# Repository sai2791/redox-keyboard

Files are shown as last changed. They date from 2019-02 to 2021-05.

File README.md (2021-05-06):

<p align="center">
Redox logo
QMK

</p>

<h3 align="center">The Redox project repository</h3>

<div align="center">

[]()




</div>

---

The Redox project is an open-source, [QMK (Quantum Mechanical Keyboard Firmware)](https://github.com/qmk/qmk_firmware) powered, ergonomic split mechanical keyboard. This repository will be used to share information about the project and instruction on how to use and assemble the Redox keyboard.

<p align="center">
Redox
</p>

**Designer's bio**: [Mattia Dal Ben (aka u/TiaMaT102)](mailto:matthewdibi@gmail.com) obtained a master's degree in Electrical Engineering with a specialization in Computer Science at the University of Udine. Currently works as a Software Engineer in R&D department for a big IoT and Embedded Computers company. Mechanical keyboard enthusiast and maker, the Redox keyboard is the result of all of his passions.

## Rationale

The Redox is a keyboard project designed with ergonomics in mind. It uses Cherry MX style mechanical switches laid out in a 7x5 columnar stagger layout with components that can easily be sourced.

The design was heavily inspired by the [Ergodox keyboard](https://www.ergodox.io/), and its main goal is to reduce the size without sacrificing too many keys, hence the name **Re**duced Ergo**dox**.

As an Ergodox user I couldn't ignore the few flaws of the original design and in a moment of arrogance I tried to fix them, thus the Redox features:
- Easier to reach thumb cluster.
- Additional easy-to-reach rotated 1.25u thumb key.
- Reduced size.
- Reduced costs (the Redox uses Arduino Pro Micro instead of the Teensy 2.0).
- Either half can be plugged in to the PC since each half can act as the master.
- Either half can work as a standalone keyboard to be used as a macropad/gaming keyboard.
- RGB backlighting support.
- 3D-printer friendly case.
- Wireless
- [VIA](https://caniusevia.com/) compatible (thanks to [Harshit Goel](https://github.com/harshitgoel96))

## Related projects

- [**Redox handwire**](https://www.thingiverse.com/thing:2704567): The first incarnation of the Redox keyboard. It consists of a 3D-printed case and a handwired matrix.
  - [Tilted Redox case](https://www.thingiverse.com/thing:2767216): tilted case for the Redox prototype by jschloer.
  - [couscous-kbd](https://gitlab.com/cschalkwijk/couscous-kbd): Redox-inspired parametric OpenSCAD keyboard design.
  - [Redox tenting kit](https://www.thingiverse.com/make:484843): modified base to support tenting, mini-USB for the interconnect, and a hole for microswitch for reset needed when uploading new firmware by [Lenbok](https://github.com/Lenbok).
  - [Iris-inspired Redox case](https://github.com/Lenbok/scad-redox-case): a case inspired both by the Redox rev1.0 and the Iris designed with OpenSCAD by [Lenbok](https://github.com/Lenbok).
  - [Redodactyl keyboard](https://www.reddit.com/r/MechanicalKeyboards/comments/9j5pw5/enter_the_redodactyl_first_build/): handwired 3D printed Dactyl-inspired Redox variant by u/darknao.
- [**Redox Manuform**](https://www.thingiverse.com/thing:3503380): full rework of the Redox case inspired by the Dactyl Manuform. Designed by [Fosk\_LL](https://www.thingiverse.com/Fosk_LL/about).
- [**Redox rev1.0**](https://github.com/mattdibi/redox-keyboard/tree/master/redox): the Redox rev 1.0 is the first commercially available version of the Redox keyboard.
	- Rev1.0 PCBs: available at [Falbatech's store](https://falba.tech/product/redox-pcb-electrical-boards-set-of-2/)
    - Firmware sources:
        - [QMK firmware for Redox](https://github.com/mattdibi/qmk_firmware/tree/master/keyboards/redox)
	- 3D-printable cases:
        - [3D printable case](https://www.thingiverse.com/thing:2886662), freely available.
        - [Redox keyboard case (high profile)](https://www.thingiverse.com/thing:3825752), by [Michele Ferri](https://www.thingiverse.com/sako83/about).
        - [Travel-friendly Redox Keyboard case](https://www.thingiverse.com/thing:3607303), by [Fosk\_LL](https://www.thingiverse.com/Fosk_LL/about).
        - [Redox Neodox case](https://github.com/Pastitas/Redox-neodox-Case), by [Pastitas](https://github.com/Pastitas)
	- Commercially available cases:
		- [Falbatech's bamboo cases with tilt kit](https://falba.tech/product/redox-standard-lift-bamboo-wood-case-with-oil-finish/)
		- [Falbatech's fullhand bamboo cases](https://falba.tech/product/redox-fullhand-bamboo-wood-case-with-oil-finish-ver-2/)
		- [Falbatech's PVC cases](https://falba.tech/product/redox-standard-pvc-white-case/)
- [**Redox rev1.0W**](https://github.com/mattdibi/redox-keyboard/tree/master/redox-w): the Redox rev 1.0W is the wireless version of the Redox keyboard.
    - Rev1.0W PCBs: available at [Falbatech's store](https://falba.tech/product/redox-wireless-pcb-electrical-boards-set-of-2/)
    - Firmware sources:
        - [QMK firmware for Redox wireless](https://github.com/mattdibi/qmk_firmware/tree/master/keyboards/redox_w)
        - [Nordic MCUs firmware for Redox wireless](https://github.com/mattdibi/redox-w-firmware)
	- 3D-printable cases:
        - [3D printed case](https://github.com/mattdibi/redox-keyboard/tree/master/redox-w/case), freely available.
        - [Redox Neodox case](https://github.com/Pastitas/Redox-neodox-Case), by [Pastitas](https://github.com/Pastitas)
    - Commercially available cases:
        - [Falbatech's bamboo and aliminium cases](https://falba.tech/product/redox-wireless-standard-lift-bamboo-wood-case-with-oil-finish/)
		- [Falbatech's fullhand bamboo cases](https://falba.tech/product/redox-wireless-standard-lift-bamboo-wood-case-with-oil-finish-ver-1/)
		- [Falbatech's PVC cases](https://falba.tech/product/redox-wireless-standard-pvc-white-case/)
- [**Redox rev2.0WHS**](https://github.com/mattdibi/redox-keyboard/tree/master/redox-w): the Redox rev 2.0WHS is the wireless hot-swappable version of the Redox keyboard.
    - Rev2.0WHS PCBs: gerber files available [here](https://github.com/mattdibi/redox-keyboard/tree/master/redox-w/rev2.0WHS/pcb)
    - Firmware sources:
        - [QMK firmware for Redox wireless](https://github.com/mattdibi/qmk_firmware/tree/master/keyboards/redox_w)
        - [Nordic MCUs firmware for Redox wireless](https://github.com/mattdibi/redox-w-firmware)
	- 3D-printable case:
        - [3D printed case](https://github.com/mattdibi/redox-keyboard/tree/master/redox-w/rev2.0WHS/case), freely available.

## Layout

<p align="center">
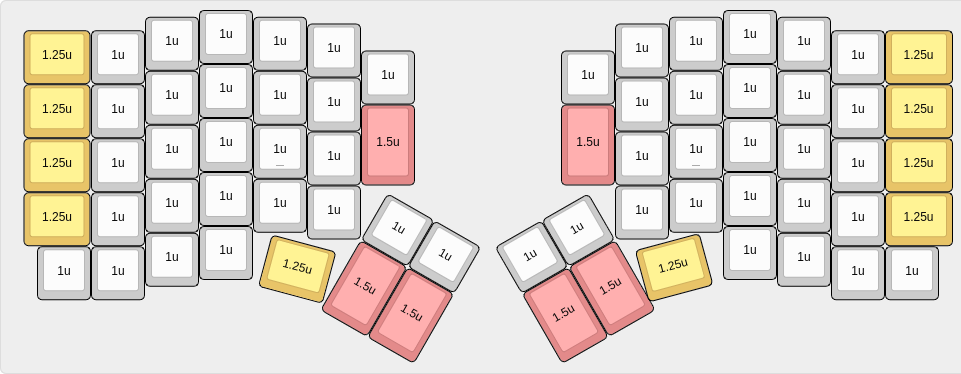
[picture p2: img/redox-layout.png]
Redox layout

</p>

### Keycaps

| Size  | Qty | Notes |
|---|:---:|:---:|
| 1.5u  | 6 | |
| 1.25u |  10 | You can get away with 8 if you use two 1u keycaps for the 1.25u rotated keys |
| 1u |  54 | |

> :information_source: On [pimpmykeyboard.com](https://pimpmykeyboard.com/sa-1976-keyset-two-shot/) site you can find a SA 1976 keyset kit specifically made for the Redox keyboard: the "Ergo Redox kit (12 keys)".

## Affiliations

In partnership with Falbatech you can now use the code "**mattdibi05**" on Falbatech's store for a 5% OFF special discount.

## Donations

If you've read this far and found something useful, please consider donating to help me maintain and further develop this project.

<p align="center">
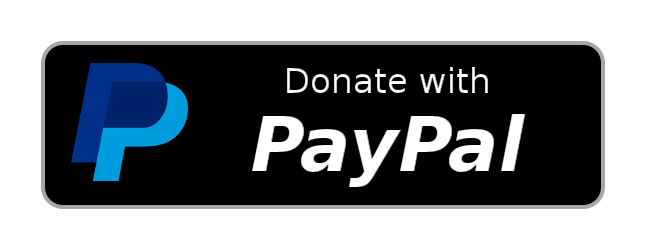
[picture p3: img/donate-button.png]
Donate button

</p>

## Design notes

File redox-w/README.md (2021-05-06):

## Redox-W (Wireless)

The Redox-W is the wireless version of the Redox keyboard, it comes in two flavours:

- **Rev 1.0W**: The first revision of the Redox Wireless.
- **Rev 2.0WHS**: Hot-swappable version of the Redox Wireless. It comes with some range improvements and limited compatibility with Rev1.0W cases (more on that in the [dedicated section](#case-compatibility)).

The two hardware revision share the firmware and the receiver dongle. In this page you'll find assembly instructions for both versions of the keyboard.

## Summary

  - [Bill of materials](#bill-of-materials)
  - [Receiver Assembly](#receiver-assembly)
  - [Transmitters Assembly](#transmitters-assembly)
    - [Rev 1.0W transmitters assembly](#rev-10w-transmitters-assembly)
    - [Rev 2.0WHS transmitters assembly](#rev-20whs-transmitters-assembly)
  - [Firmware](#firmware)
  - [Battery usage](#battery-usage)
  - [Case compatibility](#case-compatibility)

## Bill of materials

#### Transmitters

| Qty | Item | Notes |
|----:|---|---|
| 2 | Redox Wireless Transmitters PCB | Available versions: [Rev.1.0W](https://falba.tech/), [Rev.2.0WHS](https://www.pcbway.com/project/shareproject/Redox_Wireless_rev2_0WHS.html) |
|  70 | Cherry MX compatible switches | |
|  70 | Kailh PCB sockets CPG151101S11 | Rev.2.0WHS **only** |
| 2 | YJ-14015 modules (Core51822B clones) | [aliexpress](https://www.aliexpress.com/item/NRF51822-Core51822-BLE-4-0-Bluetooth-2-4G-Wireless-Module-Antenna-Board-For-ULP-SPI-I2C/32842154172.html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,searchweb201602_1_10065_10068_10843_10059_10884_10887_10696_100031_10084_10083_10103_10618_10304_10307_10820_10821_10302,searchweb201603_60,ppcSwitch_5&algo_expid=1dded059-5054-4890-bcc4-6face1150a21-1&algo_pvid=1dded059-5054-4890-bcc4-6face1150a21&priceBeautifyAB=0)
|  70 | SOD-123 1N4148/1N4148W diodes | 1N4148 THT diodes can also be used |
| 2 | Keystone 3034 SMT battery holders | [digikey](https://www.digikey.com/product-detail/en/keystone-electronics/3034/36-3034-ND/4499289)|
| 2 | JS102011SAQN SMT slide switch | [digikey](https://www.digikey.com/product-detail/en/c-k/JS102011SAQN/401-1999-1-ND/1640114)|
| 2 | Right angle 0.1" header (1x4pin) | |

#### Receiver

| Qty | Item | Notes |
|----:|---|---|
| 1 | Redox receiver PCB | [PCB manufacturing link](https://www.pcbway.com/project/shareproject/Redox_Wireless_Receiver.html) |
| 1 | YJ-14015 module (Core51822B clone) | [aliexpress](https://www.aliexpress.com/item/NRF51822-Core51822-BLE-4-0-Bluetooth-2-4G-Wireless-Module-Antenna-Board-For-ULP-SPI-I2C/32842154172.html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,searchweb201602_1_10065_10068_10843_10059_10884_10887_10696_100031_10084_10083_10103_10618_10304_10307_10820_10821_10302,searchweb201603_60,ppcSwitch_5&algo_expid=1dded059-5054-4890-bcc4-6face1150a21-1&algo_pvid=1dded059-5054-4890-bcc4-6face1150a21&priceBeautifyAB=0) |
| 1 | Arduino Pro Micro compatible microcontroller  | |
| 1 | 1117 3.3v regulator in SOT223 | [digikey](https://www.digikey.com/product-detail/en/diodes-incorporated/AZ1117IH-3.3TRG1/AZ1117IH-3.3TRG1DICT-ND/5699682)|
| 2 | 330 Ohm 0805(2012 metric) SMD resistors | Default configuration. Values depends on LED color, see [below](#resistor-values)|
| 2 | 220 Ohm 0805(2012 metric) SMD resistors | Default configuration. Values depends on LED color, see [below](#resistor-values)|
| 3 | 1.5k Ohm 0805(2012 metric) SMD resistors | Default configuration. See [below](#resistor-values)|
| 1 | Red 0805(2012 metric) SMD standard LED | Default configuration. |
| 1 | Blue 0805(2012 metric) SMD standard LED | Default configuration. |
| 1 | Green 0805(2012 metric) SMD standard LED | Default configuration. |
| 1 | White 0805(2012 metric) SMD standard LED | Default configuration. |
| 1 | Through hole momentary switch | Dimensions 6mm x 6mm x 4.3mm |
| 1 | Right angle 0.1" header (1x4pin) | |
| 2 | Straight 0.1" header (1x6pin) | |

> :information_source: You can also use the [Mitosis receiver](https://github.com/reversebias/mitosis-hardware/blob/master/bom/README.md) since it's almost identical, or you can build a receiver on your own.

> :warning: To program the YJ-14015 MCUs you need an ST-Link v2 programmer, these can be found on eBay or Aliexpress for as little as 2$ shipped. See [picture below](#nordic-mcus-firmware).

##### Resistor values

If you want to customize your LEDs color or save a few bucks by ordering the LED all the same color you can refer to this section for choosing the correct resistor values. Otherwise you can refer to the [default configuration](#default-configuration).

There are two sets of resistor that you need for the receiver.

- The voltage divider resistors (`R1`, `R2` and `R3`): anything between 1.5k Ohm and 4.7k Ohm is good.
- The LEDs resistors (`R4`,`R6`,`R7` and `R8`): see the following table.

| LED color | Vf | Suggested resistor value |
|---|---|---|
| Red | 1.7V | 330 Ohm |
| Yellow | 2.1V | 330 Ohm |
| Blue | 3.2V | 220 Ohm |
| Green | 2.2V | 330 Ohm |
| White | 3.6V | 220 Ohm |

Depending on the color you choose to use you should use the resistor listed above.

#### Default configuration

Here you can find the default configuration for the receiver assembly.

| Label | Component |
|---|---|
| D1 | Red LED |
| D2 | Blue LED |
| D3 | Green LED |
| D4 | White LED |
| R4 |  330 Ohm resistor |
| R6 |  220 Ohm resistor |
| R7 |  330 Ohm resistor |
| R8 |  220 Ohm resistor |
| R1 | 1.5k Ohm resistor |
| R2 | 1.5k Ohm resistor |
| R3 | 1.5k Ohm resistor |

## Receiver Assembly

The receiver assembly is pretty straightforward, you can install the components in any order you like with the exception of the YJ-14015: it should be installed **after** the right angled header (PROGR_HEADER1). Suggested assembly order:

1. Solder D1, D2, D3 and D4 LEDs. See [image](#leds-installation-detail) for orientation.
2. Solder R4, R6, R7 and R8 resistors.
3. Solder R1, R2 and R3 resistors.
4. Solder the AMS1117.
5. Solder the Arduino Pro Micro headers.
6. Solder the programming headers. I suggest you to cut the excess of the header **before** soldering the headers. You should stay as flush to the PCB surface as possible since the controller will be soldered above the headers. Use some masking tape to help you keep the header in place while soldering.
7. Solder the YJ-14015. I suggest you to glue it in place or use some masking tape to help you during soldering.
8. Upload the firmware and you're done.

##### Assembled PCB, front

<p align="center">
Assembled receiver PCB, front.
</p>

##### Assembled PCB, back

<p align="center">
Assembled receiver PCB, back.
</p>

##### LEDs installation detail

<p align="center">
Assembled receiver PCB, LEDs installation detail.
</p>

> :information_source: Please note that here I installed 220 Ohm resistors because I used only blue and white LEDs as I only had those laying around. You should use the resistor values suggested [here](#resistor-values) or follow the [default configuration](#default-configuration).

## Transmitters Assembly

### Rev 1.0W transmitters assembly

<p align="center">
Wireless redox PCBs
</p>

Assembly steps:

- Solder components to PCBs (you can proceed in no particular order):
  1. Solder the YJ-14015.
  2. Solder 1N4148 diodes.
  3. Solder slider switches.
  4. Solder the battery holders. *Note*: Some solder is needed on the ground pad to contact properly with the battery. See [picture below](#battery-holder-installation-detail).
  5. Solder the programming headers.
- Fit the PCBs inside their cases.
- Add the switches to the plate.
- Solder switches to the PCB.
- Add the CR2032 batteries.
- Program the MCUs.
- Close the case.

##### Programming headers detail

<p align="center">
Programming headers detail
</p>

##### MCUs detail

<p align="center">
MCUs detail
</p>

##### Slider switch detail

<p align="center">
Slider switch detail
</p>

##### Diodes installation detail

<p align="center">
Diode installation detail
</p>

##### Battery holder installation detail

<p align="center">
Battery holder installation detail. Ground pad.
Battery holder installation detail. Assembled.
</p>

##### Left and right hand completed assembly

<p align="center">
Left and right hand completed assembly
</p>

##### Assembled PCB

<p align="center">
Wireless Redox assembled PCB
</p>

### Rev 2.0WHS transmitters assembly

<p align="center">
Redox 2.0WHS PCBs, unassembled.
</p>

Suggested assembly order (there's no wrong way of doing this because all parts can be soldered in any order):
1. Solder the YJ-14015.
2. Solder the right angle 0.1" header. To test the solder job try uploading the firmware as described in the dedicated section.
3. Solder the diodes taking into account the right orientation. The cathode side (denoted by the vertical line on the packaging) should face the squared hole on the PCB. See the [pictures](#diodes-and-hot-swap-socket-detail) for reference. If you have already assembled the Redox receiver, you can now test if the PCB is working properly by connecting the STLinkV2 debugger for supplying power to the transmitter and using a pair of pliers to short the Kailh socket pins.
4. Solder the Kailh hot-swap sockets.
5. Solder the battery holders.
6. Solder the slide switch.

##### MCUs detail

<p align="center">
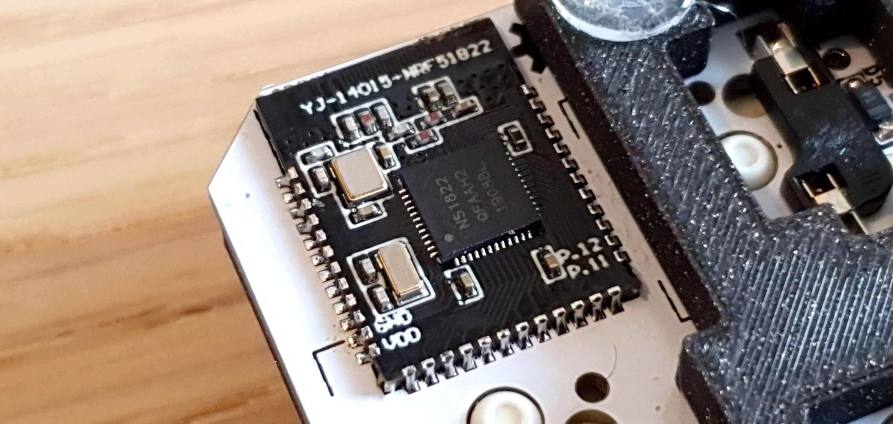
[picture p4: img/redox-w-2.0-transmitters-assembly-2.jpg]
MCUs detail 1

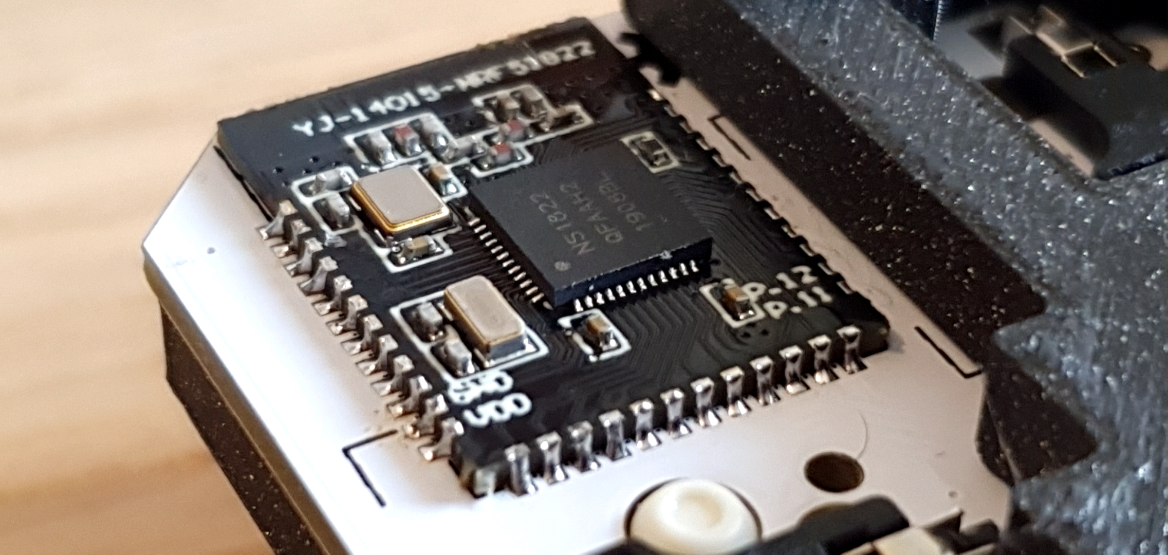
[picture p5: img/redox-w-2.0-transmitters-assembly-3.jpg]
MCUs detail 2

</p>

##### Diodes and hot-swap socket detail

<p align="center">
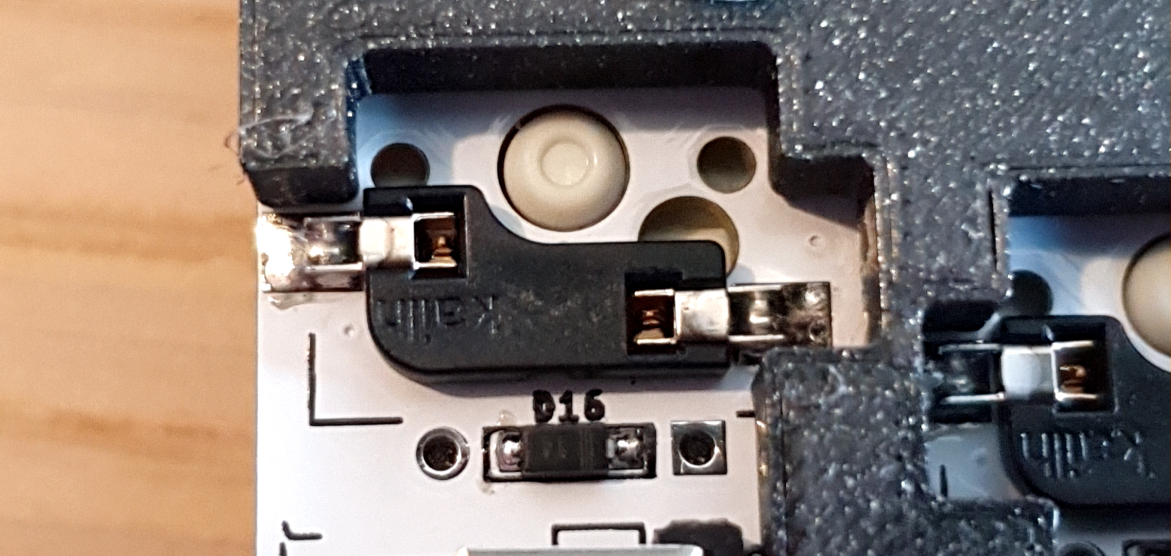
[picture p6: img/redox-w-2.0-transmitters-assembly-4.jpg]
Diode and hot-swap socket detail 1

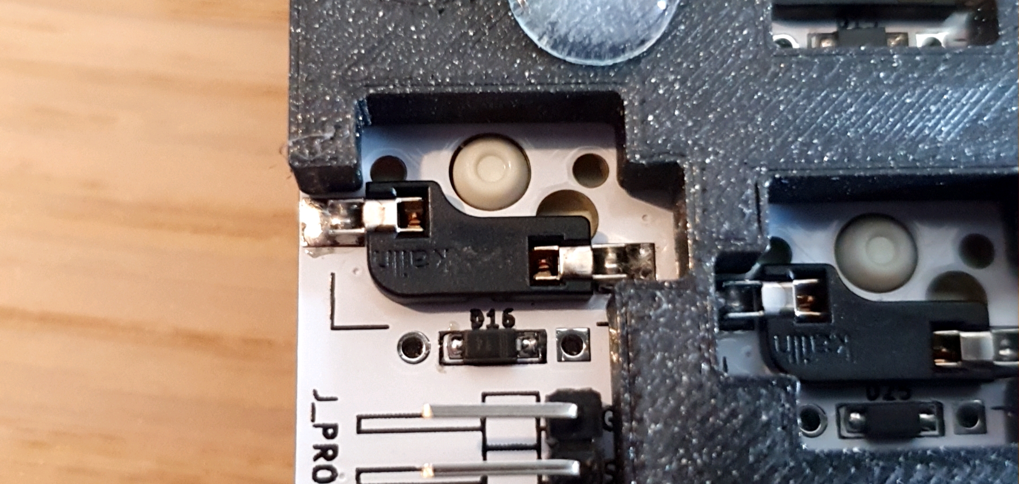
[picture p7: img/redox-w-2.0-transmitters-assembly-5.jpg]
Diode and hot-swap socket detail 2

</p>

##### Assembled PCB

<p align="center">
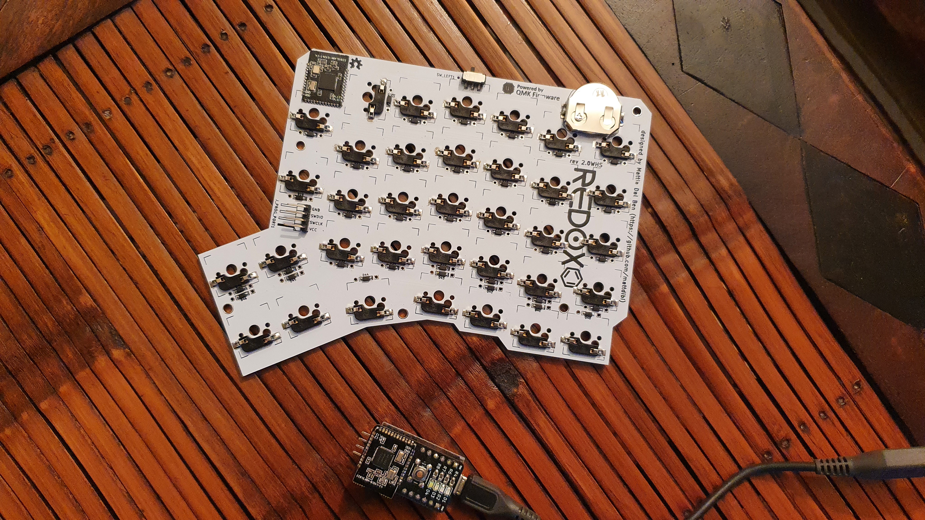
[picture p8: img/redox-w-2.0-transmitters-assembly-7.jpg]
Wireless Redox assembled PCB

</p>

##### Rev 2.0WHS 3D printed case

<p align="center">
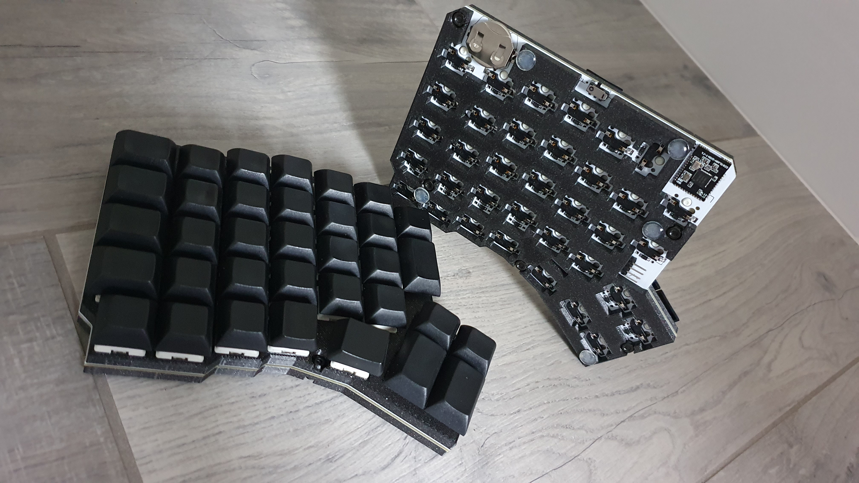
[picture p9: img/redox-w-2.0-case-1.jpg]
3D printed case

</p>

[Here](https://github.com/mattdibi/redox-keyboard/tree/master/redox-w/rev2.0WHS/case) you can find the newly designed case for the Redox 2.0 WHS. Features:
- Easy to print
- Sturdy feeling
- Minimal footprint
- Integrated sound dampening

I printed it with my Prusa Mini with 0.2 mm layer height. The STLs are for the left hand keyboard only, you'll need to mirror them along the X axis in your slicer for the right hand keyboard.

Hardware required for assembly:
- 10x M3 8 mm screws
- 10x M3 nuts

> :warning: The 3D printed case requires the use of SMD diodes. Through hole diodes will interfer witht the front plate.

> :warning: The closed back design (file: `BackplateL.stl`) was not tested at the time of this writing.

## Firmware

**Basics**: The Redox keyboard works similarly to the [Mitosis keyboard](https://github.com/qmk/qmk_firmware/tree/master/keyboards/mitosis): we have two transmitters responsible for scanning the two matrices, which then transmit the matrix status through the [Gazel protocol](https://developer.nordicsemi.com/nRF5_SDK/nRF51_SDK_v5.x.x/doc/5.2.0/html/a00140.html) to the receiver. The receiver is another YJ-14015 which receives the two matrix scans and send it through serial to the Arduino Pro Micro. The Pro Micro is responsible for running QMK and converting the bytes received by the YJ-14015 into actual keystrokes.

Firmware sources available here: [https://github.com/mattdibi/redox-w-firmware](https://github.com/mattdibi/redox-w-firmware).

You'll need to upload the firmware to the corresponding MCUs as per the following diagram:

<p align="center">
Redox-W firmware diagram.
</p>

Note that you'll need to upload the firmware for the YJ-14015 only once. Everything related to the keymap is handled by the Arduino Pro Micro and QMK Firmware, that's what you will need to modify to update the keymap.

### Step-by-step firmware upload guide

#### Arduino Pro Micro Firmware upload

Let's start by uploading the QMK firmware on the Arduino, this will help us in diagnosing problems early on. The Redox Wireless uses QMK for its firmware, follow the QMK installation instructions [here](https://docs.qmk.fm/#/getting_started_build_tools), then compile and burn the firmware as follows:

```sh
$ cd path/to/qmk_firmware
$ make redox_w:default:avrdude
```

You can find the code for the Redox here: [QMK - Redox Wireless keyboard](https://github.com/mattdibi/qmk_firmware/tree/redox_wireless/keyboards/redox_w).

In the [Redox Wireless Keyboard firmware repository](https://github.com/mattdibi/redox-w-firmware/tree/master/precompiled) I added some pre-built hex files with the default keymap for testing purposes.

#### Nordic MCUs Firmware upload using Docker

To flash the firmware files to the corresponding MCUs, you'll need an STLinkV2 debugger.

<p align="center">
ST-Link v2 programmer
</p>

##### Setup

###### Requirements

- Linux-based distro (macOS should work too but wasn't tested)
- [Docker](https://docs.docker.com/get-docker/)
- [Docker-compose](https://docs.docker.com/compose/install/)
- Download the [redox-w-firmware](https://github.com/mattdibi/redox-w-firmware) repository.

###### Download the repository

Open a terminal and download the Redox Wireless firmware repository wherever you want.

```
$ git clone https://github.com/mattdibi/redox-w-firmware.git
```

or

```
$ wget https://github.com/mattdibi/redox-w-firmware/archive/refs/heads/master.zip
```

###### Install the udev rules

Install the udev rules for the STLinkV2 programmer contained inside the repository.

```
$ cd path/to/repository/redox-w-firmare/
$ sudo cp 49-stlinkv2.rules /etc/udev/rules.d/
$ udevadm control --reload-rules && udevadm trigger
```

Plug in, or replug in the programmer after this.

###### Build the two container images

From inside the `redox-w-firmware` folder run:

```
$ docker-compose build
```

After the process completes you should see three new images:

```
$ docker images
REPOSITORY           TAG       IMAGE ID       CREATED          SIZE
redox-fw-toolchain   latest    810de995238e   16 minutes ago   896MB
redox-fw-openocd     latest    173d86d1409c   18 minutes ago   168MB
ubuntu               16.04     8185511cd5ad   4 weeks ago      132MB
```

##### Programming the receiver

###### Hook up the receiver

Hook up the ST-Link debugger to the receiver board you assembled without the Arduino. You need to connect only the `VCC`, `GND`, `SWDIO` and `SWCLK` pins of the receiver board like this:

| ST-Link Debugger | Receiver board |
|---|---|
| 3.3V | VCC |
| GND | GND |
| SWCLK | SWCLK |
| SWDIO | SWDIO |

<p align="center">
ST-Link debugger wiring.
</p>

Then plug in the ST-Link debugger into your PC.

###### Run the two images using docker compose

After connecting the STLinkV2 debugger, from inside the `redox-w-firmware` folder run:

```
$ docker-compose up
Creating redox-w-firmware_openocd_1 ... done
Creating redox-w-firmware_toolchain_1 ... done
Attaching to redox-w-firmware_openocd_1, redox-w-firmware_toolchain_1
openocd_1    | Open On-Chip Debugger 0.9.0 (2018-01-24-01:05)
openocd_1    | Licensed under GNU GPL v2
openocd_1    | For bug reports, read
openocd_1    | 	http://openocd.org/doc/doxygen/bugs.html
openocd_1    | WARNING: target/nrf51_stlink.cfg is deprecated, please switch to target/nrf51.cfg
openocd_1    | Info : auto-selecting first available session transport "hla_swd". To override use 'transport select <transport>'.
openocd_1    | Info : The selected transport took over low-level target control. The results might differ compared to plain JTAG/SWD
openocd_1    | adapter speed: 1000 kHz
openocd_1    | Info : Unable to match requested speed 1000 kHz, using 950 kHz
openocd_1    | Info : Unable to match requested speed 1000 kHz, using 950 kHz
openocd_1    | Info : clock speed 950 kHz
openocd_1    | Info : STLINK v2 JTAG v17 API v2 SWIM v4 VID 0x0483 PID 0x3748
openocd_1    | Info : using stlink api v2
openocd_1    | Info : Target voltage: 3.274320
openocd_1    | Info : nrf51.cpu: hardware has 4 breakpoints, 2 watchpoints
```

From another terminal window, you should see the two containers running with the following command:

```
$ docker ps
CONTAINER ID   IMAGE                       COMMAND                  CREATED         STATUS         PORTS     NAMES
84f606ad7e25   redox-fw-toolchain:latest   "tail -f /dev/null"      4 seconds ago   Up 3 seconds             redox-w-firmware_toolchain_1
8d0d6b5da95a   redox-fw-openocd:latest     "/bin/sh -c 'openocd…"   4 seconds ago   Up 3 seconds             redox-w-firmware_openocd_1
```

###### Build and upload the firmware

We can now build and upload the firmware by issuing the following from the `redox-w-firmware` root directory:

```
$ docker exec -it redox-w-firmware_toolchain_1 ./redox-w-firmware/redox-w-receiver-basic/program.sh
```

if everything goes well we should see the following output:

```
============================= PROGRAMMING =============================
Trying 127.0.0.1...
Connected to localhost.
Escape character is '^]'.
Open On-Chip Debugger
> reset halt
target state: halted
target halted due to debug-request, current mode: Thread 
xPSR: 0xc1000000 pc: 0x00000ba8 msp: 0x20004000
> flash write_image erase /usr/src/nRF5_SDK_11/redox-w-firmware/redox-w-receiver-basic/custom/armgcc/_build/nrf51822_xxac-receiver.hex
auto erase enabled
Unknown device (HWID 0x000000d1)
using fast async flash loader. This is currently supported
only with ST-Link and CMSIS-DAP. If you have issues, add
"set WORKAREASIZE 0" before sourcing nrf51.cfg to disable it
target state: halted
target halted due to breakpoint, current mode: Thread 
xPSR: 0x61000000 pc: 0x2000001e msp: 0x20004000
wrote 16384 bytes from file /usr/src/nRF5_SDK_11/redox-w-firmware/redox-w-keyboard-basic/custom/armgcc/_build/nrf51822_xxac-receiver.hex in 0.782274s (20.453 KiB/s)
> reset
> Connection closed by foreign host.

============================== FINISHED ===============================
```

while in the docker compose terminal we should see the following:

```
openocd_1    | Info : accepting 'telnet' connection on tcp/4444
openocd_1    | target state: halted
openocd_1    | target halted due to debug-request, current mode: Thread 
openocd_1    | xPSR: 0xc1000000 pc: 0x00000ba8 msp: 0x20004000
openocd_1    | auto erase enabled
openocd_1    | Warn : Unknown device (HWID 0x000000d1)
openocd_1    | Warn : using fast async flash loader. This is currently supported
openocd_1    | Warn : only with ST-Link and CMSIS-DAP. If you have issues, add
openocd_1    | Warn : "set WORKAREASIZE 0" before sourcing nrf51.cfg to disable it
openocd_1    | target state: halted
openocd_1    | target halted due to breakpoint, current mode: Thread 
openocd_1    | xPSR: 0x61000000 pc: 0x2000001e msp: 0x20004000
openocd_1    | wrote 16384 bytes from file /usr/src/nRF5_SDK_11/redox-w-firmware/redox-w-keyboard-basic/custom/armgcc/_build/nrf51822_xxac-receiver.hex in 0.782274s (20.453 KiB/s)
openocd_1    | Info : dropped 'telnet' connection
```

###### Shutdown the container and disconnect the programmer

We can now shutdown the containers by issuing a `Ctrl-C` inside the docker-compose terminal. After the command completes we can disconnect the STLinkV2 programmer and proceed to program the rest of the MCUs.

```
^CGracefully stopping... (press Ctrl+C again to force)
Stopping redox-w-firmware_toolchain_1 ... done
Stopping redox-w-firmware_openocd_1   ... done
```

##### Programming the two halves

###### Hook up the transmitter

Hook up the ST-Link programmer with the transmitters using the programming pins, and plug the debugger in you PC.

<p align="center">
Transmitters programming pins.
</p>

Start a OpenOCD session as seen [above](#run-the-two-images-using-docker-compose) using docker-compose and start flashing the firmware.

###### Left hand firmware flashing

From another terminal window issue the following command:

```
$ docker exec -it redox-w-firmware_toolchain_1 ./redox-w-firmware/redox-w-keyboard-basic/program_left.sh
```

You should see a similar output as above. You can now shutdown the two containers, disconnect the programmer and proceed with the next MCU.

###### Right hand firmware flashing

After having hooked up the right hand to the ST-Link debugger and started a new OpenOCD session we can upload the right hand firmware.

```
$ docker exec -it redox-w-firmware_toolchain_1 ./redox-w-firmware/redox-w-keyboard-basic/program_right.sh
```

Congratulations! You flashed the Redox-W firmware.

## Battery usage

I got the current consumption for the transmitters using a shunt resistor (10 Ohm) and an oscilloscope during transmission.

<p align="center">
Current draw for Redox-W transmitters
</p>

Data:
- Current peak of 5mA (I<sub>run</sub>) and 50us duration (t<sub>run</sub>)
- Idle consumption of 2.7uA (I<sub>idle</sub>) between peaks, that is 950us duration (t<sub>idle</sub>).

We can then calculate the average current consumption during typing (I<sub>avg</sub>) using the following:

<a href="https://www.codecogs.com/eqnedit.php?latex=I_{avg}&space;=&space;\frac{I_{run}t_{run}&plus;&space;I_{idle}t_{idle}}{t_{run}&plus;t_{idle}}&space;=&space;\frac{5{mA}*50{\mu&space;A}&plus;2.7{\mu&space;A}*950{\mu&space;s}}{1ms}&space;\simeq&space;250&space;\mu&space;A" target="_blank">I_{avg} = \frac{I_{run}t_{run}+ I_{idle}t_{idle}}{t_{run}+t_{idle}} = \frac{5{mA}*50{\mu s}+2.7{\mu A}*950{\mu s}}{1ms} \simeq 250 \mu A</a>

Knowing that the CR2032 battery is rated for 220mAh we get:

<a href="https://www.codecogs.com/eqnedit.php?latex=t_{batt}&space;=&space;\frac{C_{batt}}{I_{avg}}&space;=&space;\frac{220{mAh}}{250{\mu&space;A}}&space;\simeq&space;880h" target="_blank">t_{batt} = \frac{C_{batt}}{I_{avg}} = \frac{220{mAh}}{250{\mu A}} \simeq 880h</a>

**TLDR**: We can expect **at least 880 hours** of continuous typing on the keyboard before needing to change the batteries. Keep in mind that when you're not typing (500ms without key presses is the time interval needed for the keyboard) the transmitters go into deep sleep mode and draw only 2.7uA. So for an everyday use (4 hours a day of continuous typing) you can expect a battery life of at least a year. Obviously your mileage may vary.

> :information_source: After using my keyboard for a few years I can confirm that battery usage matches the above computations. Please note that a metallic case can greatly impact user experience and battery usage.

## Case compatibility

Revision 1.0W and 2.0WHS share a lot of similarities with the exception of a single mounting hole.

<p align="center">
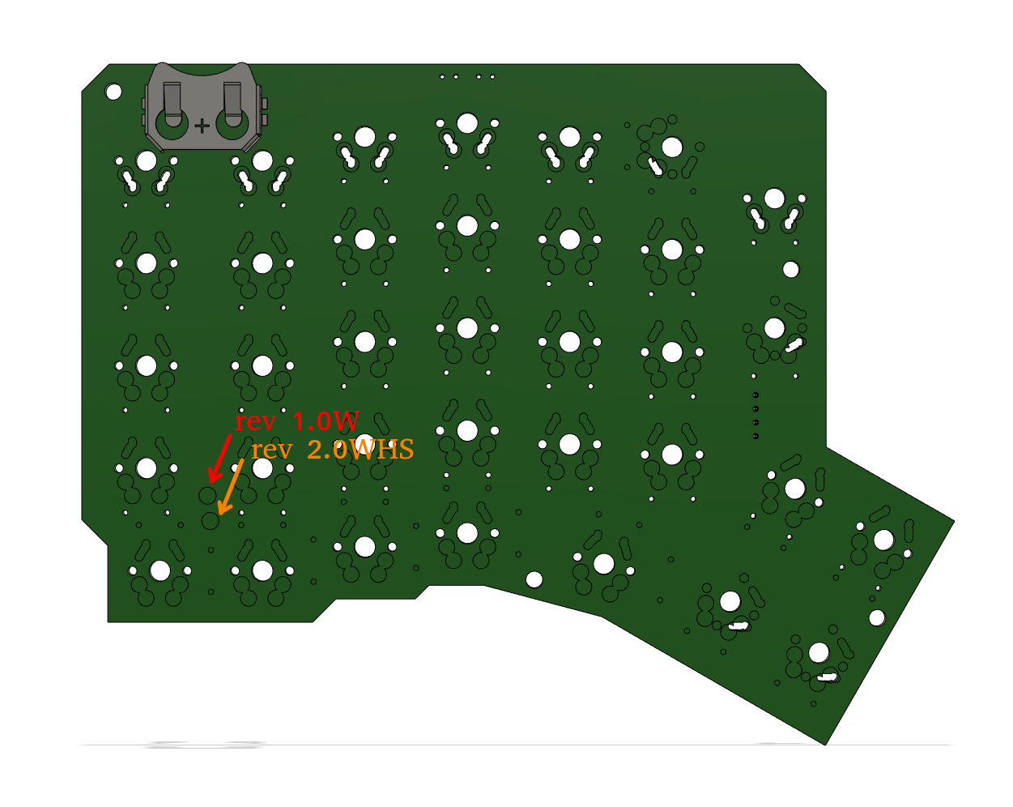
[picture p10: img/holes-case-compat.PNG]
Redox-W revisions compatibility.

</p>

As you can see from the above image, the mounting hole was moved a little lower in the rev 2.0WHS. This shouldn't compromise usability and fitment but take this into account if you want to fit a 2.0WHS PCB into a 1.0W case or vice-versa.

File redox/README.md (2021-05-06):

# Redox rev 1.0

The Redox rev 1.0 is the first commercially available version of the Redox keyboard.

Hardware availability:
  - [Falbatech](https://falba.tech/)

## Summary

  - [Bill of materials](#bill-of-materials)
  - [Other assembly guides](#other-assembly-guides)
  - [Assembly guide](#assembly-guide)
  - [Firmware](#firmware)
  - [Hot swappable mod](#hot-swappable-mod)
  - [RGB Underglow](#rgb-underglow)

## Bill of materials

| Qty | Item | Notes |
|----:|---|---|
|  70 | Cherry MX compatible switches | |
| 2 | Redox PCBs | [Available here](https://falba.tech/product/redox-pcb-electrical-boards-set-of-2/)|
|  70 | 1N4148 diodes | SMD diodes can also be used |
| 2 | PJ-320A 4 poles 3.5 mm TRRS connectors | |
| 2 | 4.7 kOhm resistors | Need to be soldered on one half only |
| 2 | Through hole momentary switch | Dimensions 6mm x 6mm x 4.3mm |
| 2 | Arduino Pro Micro compatible microcontrollers | Beware of the infamous Green Pro Micro, see note below. |
| 1 | TRRS cable | |
| 1 | USB micro cable | |
|  70 | Cherry MX compatible keycaps | 10x 1.25u keycaps, 6x 1.5u keycaps, 54x 1u keycaps  |
|  14 | WS2812/WS2812B leds | Optional RGB-underglow |

> :warning: Pay attention to the Pro Micro you use in this project. Online you can find the infamous **Green Pro Micros** which have the same pinout of the normal Pro Micro but use a different power circuitry. Being the Redox a split keyboard that relies on detecting which side is directly powered to find which side is the master, these clones are not suited for the task. A more detailed explanation [here](http://www.40percent.club/2017/09/green-pro-micro.html). Please note that they can come in different colors, not necessarily green.

## Other assembly guides

External links to some other guides to building the Redox keyboard:

- ["*Build your own keyboard*"](https://medium.com/@costask/build-your-own-keyboard-5df65cb68839) by @costask.
- [Imgur build log](https://imgur.com/a/a6ck2Nc) (3D printed case).
- ["*First Homebrew Keyboard -redox Build Log-*"](https://x1.inkenkun.com/archives/6007) by [インケンch](https://www.youtube.com/channel/UCXJZdip7JmW74HQHCtfYzFw) (Japanese only)
- ["*Split Keyboard Build*"](https://kubami.com/articles/split-keyboard-build/) by Kuba Misiorny @kubami.

### Video guides

Two great video guides by [インケンch](https://www.youtube.com/channel/UCXJZdip7JmW74HQHCtfYzFw) (Japanese only).

<p align="center">
<a href="http://www.youtube.com/watch?v=EVRlU_eR9j4">Redox hardware assembly</a>
<a href="http://www.youtube.com/watch?v=jRIRdfIIa1Q">Redox firmware</a>
</p>

Another great guide by [Antonio Raptors](https://www.youtube.com/channel/UCNYbiq6AH8AdYTKMokKaviQ) (Spanish only).

<p align="center">
<a href="https://www.youtube.com/watch?v=wRvfs1tUpZ4">Como hacer un teclado mecánico para diseño / gaming - REDOX ESPAÑOL</a>
</p>

## Assembly guide

<p align="center">
Redox PCBs
</p>

Installation steps:

- Solder components:
  1. Solder 1N4148 diodes. Keep the diode legs for the right hand controller installation.
  2. Solder PJ-320A connectors.
  3. Solder momentary switches.
  4. Solder 4.7k Ohm resistors **on one half only**. If you are going for the RGB-underglow ignore this step.
  5. Solder the Pro Micro header pins (**do not solder the Pro Micro controllers yet**). This step may differ depending on which case you're using. Refer to the following:
    * See 3D-Printed case [right hand controller installation detail](#3d-printed-case-assembly).
    * See Falbatech's [bamboo case](#falbatechs-bamboo-case-assembly).
    * See [socketed Pro Micro installation guide](#pro-micro-sockets).
  6. Optional see [RGB-underglow instructions](#rgb-underglow).
- Flip the PCBs.
- Solder switches to the PCB.
  * If you want hot swappable switches, see
    [the hot swappable switch instructions](#hot-swappable-switches).
- Flip the PCBs again.
- Solder Pro Micros to the header pins **following the PCB labeling**. The Pro Micro on the right half should be installed with the bottom facing the Redox PCB, the Pro Micro on the left half should be installed with the bottom facing away from the PCB. See [pictures](#left-hand-back-side-1) for details.

##### Right hand back side:
<p align="center">
Right hand back side
</p>

##### Left hand back side:
<p align="center">
Left hand back side
</p>

##### Diode installation detail:
<p align="center">
Diode installation detail
</p>

### 3D Printed case assembly

To lower the build costs I designed a 3D printable case which you can find in this repository or on [thingiverse](https://www.thingiverse.com/thing:2886662), feel free to modify it to best suit your needs.

<p align="center">
3D printed case
</p>

Parts:

| Qty | Item | Notes |
|----:|---|---|
| 1 | Left top plate | [RedoxRev1TopLeft.STL](https://github.com/mattdibi/redox-keyboard/blob/master/redox/case/RedoxRev1TopLeft.STL)|
| 1 | Left bottom | [RedoxRev1BottomLeft.STL](https://github.com/mattdibi/redox-keyboard/blob/master/redox/case/RedoxRev1BottomLeft.STL)|
| 1 | Right top plate | [RedoxRev1TopRight.STL](https://github.com/mattdibi/redox-keyboard/blob/master/redox/case/RedoxRev1TopRight.STL)|
| 1 | Right bottom | [RedoxRev1BottomRight.STL](https://github.com/mattdibi/redox-keyboard/blob/master/redox/case/RedoxRev1BottomRight.STL)|
|  10 | M3 x 8mm (or 5mm) screws | |

For the Pro Micro installation on the right hand use the diodes legs leftover from previous steps as this will make the controller's USB port much closer to the PCB, this is needed for the USB connector to fit in the 3D printed case. If you're using Falbatech's bamboo case this is not needed and you can use standard header pins. Right hand controller installation detail:

1. Use a breadboard to keep the diode's legs from falling.
2. Solder the diode's legs in place. You want to have the Pro Micro as close to the Redox's PCB as possible.
3. Cut the excess.
4. Apply some electrical tape under the controller to prevent shorts.
5. Install your preferred switches (**remember: the controller installation is the last step**).
6. Solder the controllers in place.

<p align="center">
Right hand controller installation detail
Right hand controller installation detail
</p>

Here's some measurements of the Pro Micro installation:

<p align="center">
Right hand controller installation detail
</p>

### Falbatech's bamboo case assembly

If you're using Falbatech's bamboo case the use of the diode's legs is not needed and you can use standard header pins

<p align="center">
Falbatech's case assembly
</p>

## Firmware

> :warning: If you have a Redox with RGB backlight installed you **MUST** use the serial connection. For details see [the RGB underglow firmware instructions.](#rgb-underglow)

The Redox uses QMK for its firmware, follow the QMK installation instructions [here](https://docs.qmk.fm/#/getting_started_build_tools), then compile and burn the firmware on both halves as follows:

```sh
$ cd path/to/qmk_firmware
$ make redox/rev1:default:avrdude
```

After issuing this command you should see the following output:

```sh
Detecting USB port, reset your controller now.....
```

Now you should reset the Pro Micros using the reset button as seen in the following picture:

<p align="center">
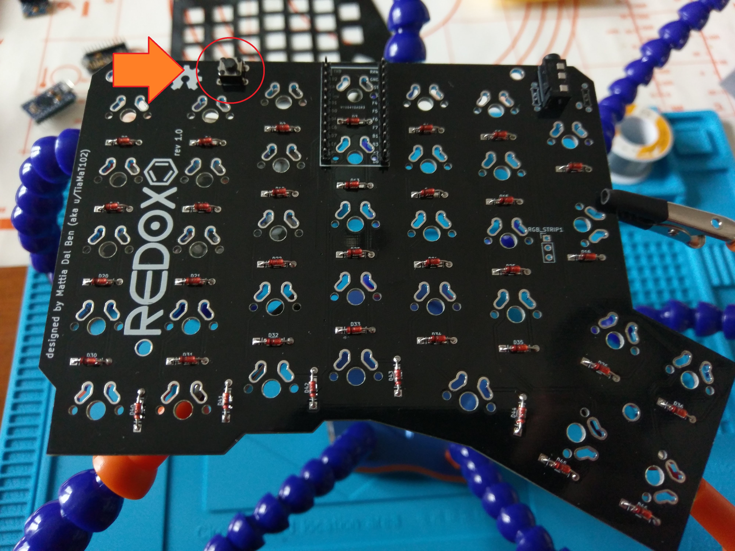
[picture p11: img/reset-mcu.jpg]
Reset button

</p>

> :warning: You always need to burn the firmware on **BOTH** halves of the keyboard.

> :warning: Failing to upload Redox Firmware on Linux. Please refer to [issue #8060](https://github.com/qmk/qmk_firmware/issues/8060) of QMK firmware.

You can find the code for the Redox here: [QMK - Redox keyboard](https://github.com/qmk/qmk_firmware/tree/master/keyboards/redox).

In the [firmware/](https://github.com/mattdibi/redox-keyboard/tree/master/redox/firmware) folder I added some pre-built hex files with the default keymap for testing purpose. You can upload the firmware binaries directly using the command below:

```sh
avrdude -p atmega32u4 -P $(COM_PORT) -c avr109 -U flash:w:redox_rev1_default.hex
```

### Setting EE_hands to use either hands as master
If you define `EE_HANDS` in your `config.h`, you will need to set the EEPROM for the left and right halves.

The EEPROM is used to store whether the half is left handed or right handed. This makes it so that the same firmware file will run on both hands instead of having to flash left and right handed versions of the firmware to each half. To flash the EEPROM file for the left half run:
```
$ cd path/to/qmk/folder
avrdude -p atmega32u4 -P $(COM_PORT) -c avr109 -U eeprom:w:"./quantum/split_common/eeprom-lefthand.eep"
// or the equivalent in dfu-programmer
```
and similarly for right half
```
avrdude -p atmega32u4 -P $(COM_PORT) -c avr109 -U eeprom:w:"./quantum/split_common/eeprom-righthand.eep"
// or the equivalent in dfu-programmer
```

> :warning: Replace `$(COM_PORT)` with the port of your device (e.g. `/dev/ttyACM0`)

After you have flashed the EEPROM, you then need to set `EE_HANDS` in `keyboard/redox/keymaps/default/config.h` like so:

```c++
// ...
/* Use I2C or Serial, not both */

// #define USE_SERIAL
#define USE_I2C

/* Select hand configuration */

// #define MASTER_LEFT
// #define MASTER_RIGHT
#define EE_HANDS

#undef RGBLED_NUM
#define RGBLIGHT_ANIMATIONS
// ...
```

Then rebuild the hex files and reflash.

Note that you need to program both halves, but you have the option of using different keymaps for each half. You could program the left half with a QWERTY layout and the right half with a Colemak layout using bootmagic's default layout option. Then if you connect the left half to a computer by USB the keyboard will use QWERTY and Colemak when the right half is connected.

## Hot swappable mod

With a few modifications to the original design, it is possible to make a
Redox with hot swappable switches and socketed Pro Micros. This was tested
with Falbatech's PCBs and PVC cases. The switch hotswap mod should work with
any case with a top plate that the switches snap into, with about a millimeter
of extra clearance between the top plate and the PCB, and another extra half
millimeter or so between the PCB and case bottom. If your (non-Falba) PCBs
have particularly small diameter thru-holes for switch pins, check the
Mill-Max 7305 spec sheet to ensure the receptacles will fit.

### Extended bill of materials

| Qty | Item | Notes |
|----:|---|---|
| 1 | Peel-A-Way Sockets (82 pin strip) | Available from [keeb.io](https://keeb.io/collections/frontpage/products/peel-a-way-sockets-for-pro-micros?variant=12972145344606)|
| 140 | Mill-Max 7305 Pin Receptacles | Available from [Digi-Key](https://www.digikey.com/product-detail/en/mill-max-manufacturing-corp/7305-0-15-15-47-27-10-0/ED1039-ND/1765737) or [Mouser](https://www.mouser.com/ProductDetail/Mill-Max/7305-0-15-15-47-27-10-0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)|
| 1 | Roll of Kapton tape | |

Some extra Mill-Max receptacles may come in handy, in case of soldering
mistakes or manufacturing defects.

### Pro Micro Sockets

<p align="center">
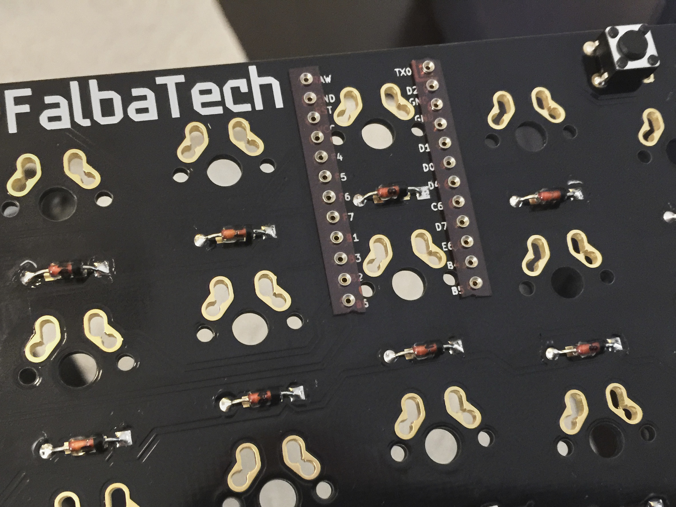
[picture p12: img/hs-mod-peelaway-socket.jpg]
Pro Micro Peel-A-Way socket top detail

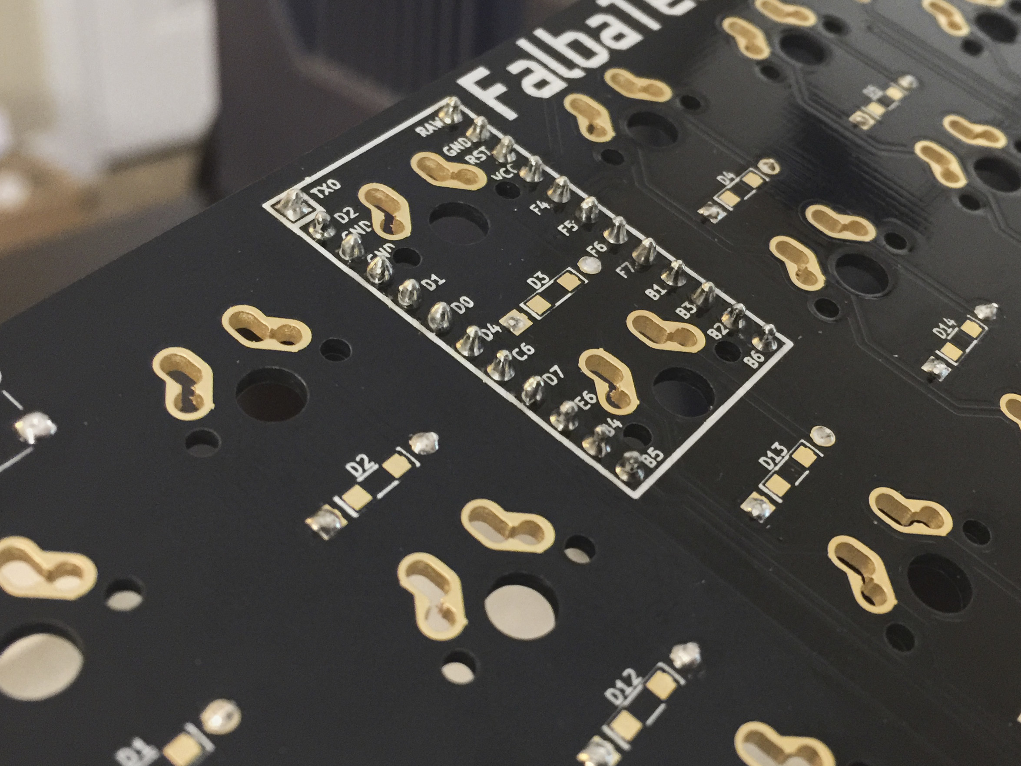
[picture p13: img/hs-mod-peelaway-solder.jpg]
Pro Micro Peel-A-Way socket solder detail

</p>

Socketing your microcontrollers will allow you to swap out broken Pro Micros,
or swap any Pro Micro pin-compatible microcontroller (with, for example, USB-C)
into a finished build. Before you begin, you'll want to follow the
[standard assembly guide steps](#assembly-guide)
for soldering 1N4148 diodes, PJ-320A connectors,
momentary switches, and any resistors you'll be using. Remember to
**trim the legs off your diodes and keep them**, as we'll be using the legs to
make pins for each Pro Micro.

Installation steps, after initial soldering:

1. Using scissors or flush cutters, cut out two 12-pin strips of Peel-A-Way
   sockets.
2. With the bottom side of the PCB (the side with the diodes, momentary
   switch, and TRRS connector visible) facing up, place the cut Peel-A-Way
   socket strips into the thru-holes where the Pro Micro headers would
   usually go.
3. Temporarily fasten the Peel-A-Way sockets to the PCB with Kapton tape.
4. Flip over the PCB.
5. Solder the sockets into the thru-holes.
6. Install your switches. This step differs depending on whether you plan
   on making your switches hotswappable:
   * For fixed, non-hotswap switches, follow [the standard assembly guide](#assembly-guide).
   * Hotswap switch builds should follow [the hot swappable switch install guide](#hot-swappable-switches).
7. Flip and orient your Pro Micro so that its labels match the labels on your
   PCB, then cover the bottom of the Pro Micro in electrical or Kapton tape
   to prevent shorts.
8. Thread the least bent of your trimmed diode legs through the thru-holes
   in your Pro Micro and into the corresponding sockets on the PCB.
9. Keeping the Pro Micro as level as possible, solder the diode legs to the
   Pro Micro. It may help to keep a USB cable attached to the Pro Micro, to
   help ensure the port ends up in a usable orientation.
10. Trim the excess length of the diode legs off of the top of the Pro Micro.
11. Repeat these steps for the other half of your Redox.

### Hot Swappable Switches

> :warning: A few things to keep in mind:
> - Some switch pins (so far, Kailh Box Royals) may be slighly too wide to
>   fit the Mill-Max receptacle. When in doubt, try it with spare receptacles.
> - The only thing keeping the PCB attached to the top plate is the switches;
>   if you remove too many (more than half per side), the PCB will detach and
>   fall into the case. Try to swap only a few switches at once.

<p align="center">
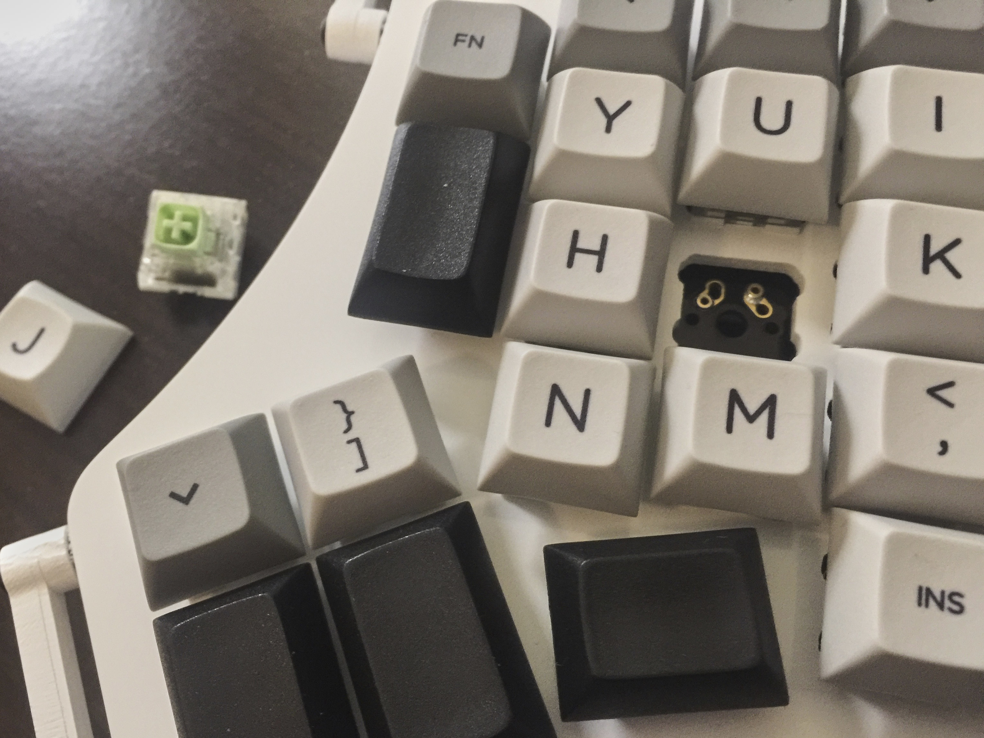
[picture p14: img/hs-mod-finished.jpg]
Finished Redox with hotswap switches

</p>

To build a Redox with hot swappable switches, follow these steps instead of
the switch installation instructions in the standard build guide. Soldering
Mill-Max receptacles is trickier than soldering bare switch pins; a small
iron tip, small diameter solder, and relatively low temperatures are
recommended.

1. Take each of your switches and push a Mill-Max receptacle fully onto each
   pin. One end of the receptacle has a small ring around it that makes it
   wider than the other end; the receptacle should be oriented so that the
   wide end is touching the switch housing (and will end up on the top,
   plate-facing side of the PCB in the assembled keyboard).
2. Snap switches into each of the four corners of your top plate, and two
   more into the mounting holes that will be directly above the Pro Micro
   in the assembled keyboard.
3. Flip over the top plate and install the PCB.
   - The receptacles might be a tight fit for the PCB thru-holes; if so,
     press the PCB into the switches to make sure the PCB is fully mounted
     and level.
4. Install the rest of the switches, starting from the outside edges of the
   plate and moving inward.
   - Initially, installing switches will likely shift the surrounding unsoldered
     switches and the PCB out of position, so pinch any jostled switches and
     the PCB back together as you go.
   - Be careful not to apply too much pressure to the stem of the switch, as
     this could damage it.
5. Solder your switches, starting from the corners then going from the outside
   edges to the inner switches in roughly the same order as the previous step.
   - Before soldering each switch, apply pressure to the top of the switch
     and the bottom of the PCB a final time to ensure the switch, plate, and
     PCB are all properly seated.
   - Apply heat to the pin receptacle and pad, then melt your solder onto
     the pad. You will want a "volcano" shaped solder joint which fully
     encircles the bottom of the receptacle, but doesn't fill its inner
     surface.
   - If you need to test that you haven't accidentally soldered a pin
     permanently into its receptacle by allowing solder to spill into the
     inner surface of the receptacle, you can try and temporarily remove
     the switch as you would during a hot swap. Use a switch puller to depress
     the tabs on the top and bottom of the switch (or the left and right for
     the flipped 1.5u key switches), and gently pull up on the switch until
     it is free of the keyboard. Note that if the switch and receptacles are
     still hot, it might take some extra effort to pull out the switch.
     Next, snap the switch back into its socket, and fix any unsoldered
     switches that were knocked out of place during this process.
6. Repeat these steps for the other side of the keyboard.

##### Installing Mill-Max receptacles onto switch pins:
<p align="center">
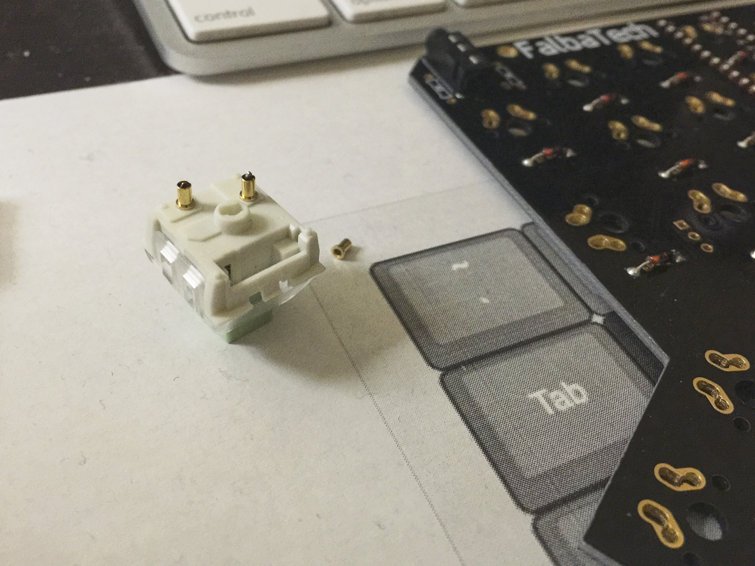
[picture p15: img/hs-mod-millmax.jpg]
Mill-Max receptacle installation

</p>

##### Pins, receptacles, and PCB in proper alignment:
<p align="center">
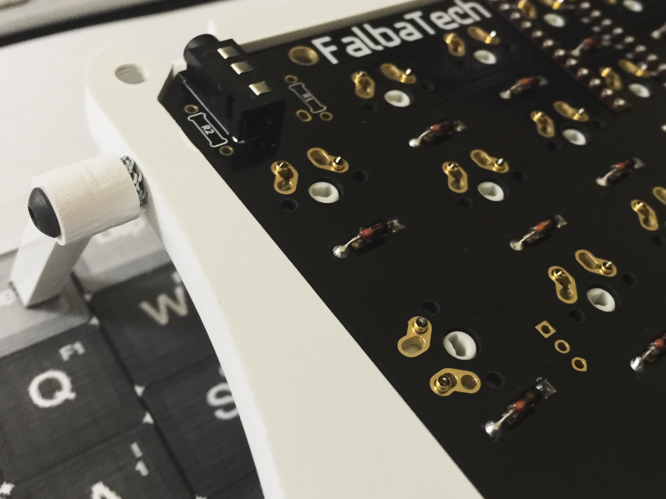
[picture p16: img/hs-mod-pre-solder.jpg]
Proper alignment of receptacles, pins, and PCB

</p>

##### Soldered hot swap receptacles:
<p align="center">
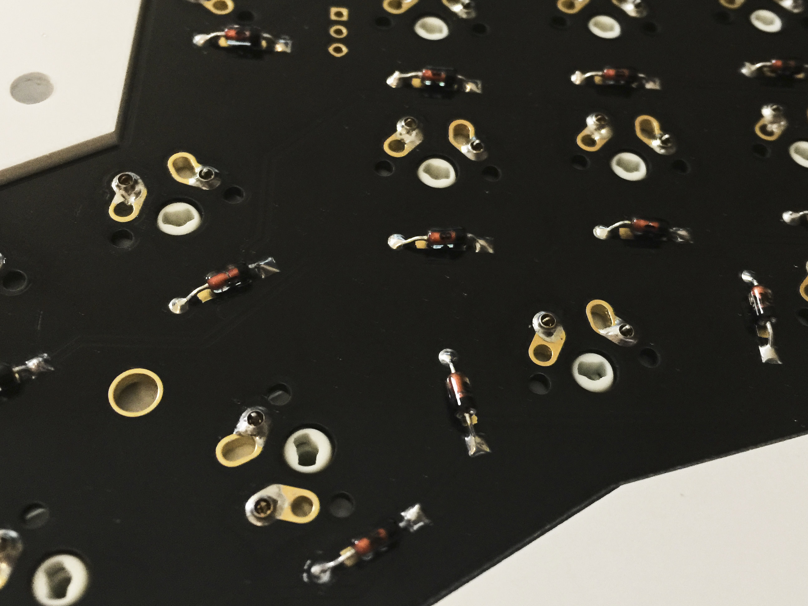
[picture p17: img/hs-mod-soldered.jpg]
Soldered hot swap receptacles

</p>

## RGB Underglow

> :warning: With this configuration:
> - You don't need to solder the 4.7k resistors since the I2C connection won't be used.
> - You can use only one hand as master.

Parts:
- [ ] WS2812/WS2812B LED strip
- [ ] 24 AWG (or smaller) stranded wire (white, red, black are good choices)

Data connection:

```
Led strip Headers -> DIN -> DO -> TRRS pad -> (TRRS to other side) -> TRRS pad -> DIN
```

### Assembly: LEFT hand as master (usually plugged in to the PC)
- On the LEFT hand:
  1. Solder the LED Strip headers as seen in the pictures below.
  2. Solder the DO Pin of the RGB strip to the TRRS pad as seen in the figures below.
- On the RIGHT hand:
  1. Solder VCC and GND of the RGB strip to the LED Strip headers.
  2. Solder the DIN Pin of the RGB strip to the TRRS pad as seen in the figures below.
- Flash the firmware with the serial and RGB Backlight options on, specifying the number of LEDs installed (see instruction [here](#rgb-underglow-firmware)).

##### Left hand back side:
<p align="center">
RGB underglow left hand backside
</p>

##### Right hand back side:

<p align="center">
RGB underglow left hand backside
</p>

### Assembly: RIGHT hand as master
- On the RIGHT hand:
  1. Solder the LED Strip headers to the RGB strip.
  2. Solder the DO Pin of the RGB strip to the TRRS pad.
- On the LEFT hand:
  1. Solder VCC and GND of the RGB strip to the LED Strip headers.
  2. Solder the DIN Pin of the RGB strip to the TRRS pad.

### RGB Underglow firmware

To enable RGB backlighting you need to modify the default firmware as follows:
- Use serial communication instead of I2C.
- Set the master hand.
- Set the number of LED you installed.

To do this, modify `qmk_firmware/keyboards/redox/keymaps/default/config.h` as follows:

```c++
// ...

/* You need to use the sarial communication since we
used a cable to carry the data signal for the LED strip */
#define USE_SERIAL

/* Select hand configuration: you need to use as master
the hand that drives the LED strip */
#define MASTER_LEFT
// #define MASTER_RIGHT

/* Put the total number of led used here */
#undef RGBLED_NUM
#define RGBLIGHT_ANIMATIONS
#define RGBLED_NUM 14
#define RGBLIGHT_HUE_STEP 8
#define RGBLIGHT_SAT_STEP 8
#define RGBLIGHT_VAL_STEP 8

// ...
```

Then compile and burn the firmware on both controllers:

```sh
$ cd path/to/qmk_firmware
$ make redox/rev1:default:avrdude
```

## Layout

<p align="center">
Redox rev1.0 layout
</p>

[KLE Layout permalink](http://www.keyboard-layout-editor.com/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(%0A9%3B&@_y:-0.875&x:5.5%3B&=%25%0A5&_x:6.5%3B&=%5E%0A6%3B&@_y:-0.875&x:0.25&a:5&w:1.25%3B&=%60%0A%0A%0A%0A%0A%0ALayer%202&_a:4%3B&=!%0A1&_x:14.5%3B&=)%0A0&_a:5&w:1.25%3B&=-%0A%0A%0A%0A%0A%0ALayer%202%3B&@_y:-0.625&x:6.5%3B&=Layer%201&_x:4.5%3B&=Layer%201%3B&@_y:-0.75&x:3.5&a:4%3B&=E&_x:10.5%3B&=I%3B&@_y:-0.875&x:2.5%3B&=W&_x:1%3B&=R&_x:8.5%3B&=U&_x:1%3B&=O%3B&@_y:-0.875&x:5.5%3B&=T&_x:6.5%3B&=Y%3B&@_y:-0.875&x:0.25&a:5&w:1.25%3B&=TAB&_a:4%3B&=Q&_x:14.5%3B&=P&_a:5&w:1.25%3B&=%2F=%3B&@_y:-0.625&x:6.5&a:7&h:1.5%3B&=%5B&_x:4.5&h:1.5%3B&=%5D%3B&@_y:-0.75&x:3.5&a:4%3B&=D&_x:10.5%3B&=K%3B&@_y:-0.875&x:2.5%3B&=S&_x:1&n:true%3B&=F&_x:8.5&n:true%3B&=J&_x:1%3B&=L%3B&@_y:-0.875&x:5.5%3B&=G&_x:6.5%3B&=H%3B&@_y:-0.875&x:0.25&a:5&w:1.25%3B&=ESC&_a:4%3B&=A&_x:14.5%3B&=%2F:%0A%2F%3B&_a:5&w:1.25%3B&='%3B&@_y:-0.375&x:3.5&a:4%3B&=C&_x:10.5%3B&=%3C%0A,%3B&@_y:-0.875&x:2.5%3B&=X&_x:1%3B&=V&_x:8.5%3B&=M&_x:1%3B&=%3E%0A.%3B&@_y:-0.875&x:5.5%3B&=B&_x:6.5%3B&=N%3B&@_y:-0.875&x:0.25&a:5&w:1.25%3B&=SHIFT&_a:4%3B&=Z&_x:14.5%3B&=%3F%0A%2F%2F&_a:5&w:1.25%3B&=SHIFT%3B&@_y:-0.375&x:3.5%3B&=*%0A%0A%0A%0A%0A%0AALT&_x:10.5%3B&=Left%3B&@_y:-0.875&x:2.5%3B&=-&_x:12.5%3B&=Down%3B&@_y:-0.75&x:0.5%3B&=GUI&=+&_x:14.5%3B&=Up&=Right%3B&@_r:15&y:-2.625&x:5.75&w:1.25%3B&=%5C%0A%0A%0A%0A%0A%0ACTRL%3B&@_r:30&rx:6.5&ry:4.25&y:-1%3B&=PgUp&=PgDn%3B&@_h:1.5%3B&=Back%0A%0A%0A%0A%0A%0Aspace&_h:1.5%3B&=Del%3B&@_r:-30&rx:13&y:-1&x:-2%3B&=Home&=End%3B&@_x:-2&h:1.5%3B&=Enter&_h:1.5%3B&=Space%3B&@_r:-15&rx:0&ry:0&y:7.75&x:11.75&w:1.25%3B&=ALT)

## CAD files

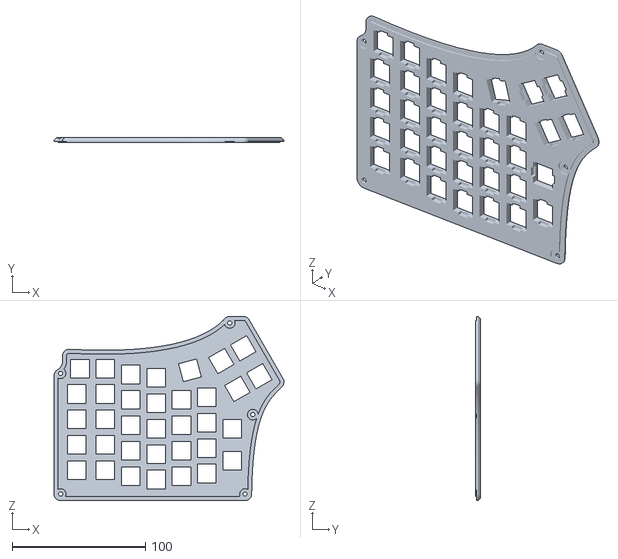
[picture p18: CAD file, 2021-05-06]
redox-w/rev1.0W/case/RedoxWirelessRev1TopLeft.STL
172.6 x 4.00 x 138.4

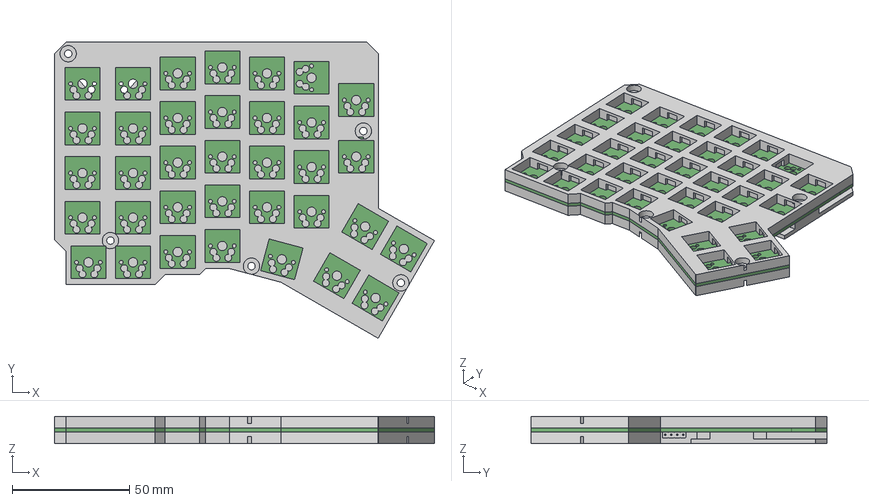
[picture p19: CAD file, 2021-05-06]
redox-w/rev2.0WHS/case/RedoxRev2.0WHSCasev15.step
162.2 x 126.5 x 11.6 mm
Backplate
Frontplate

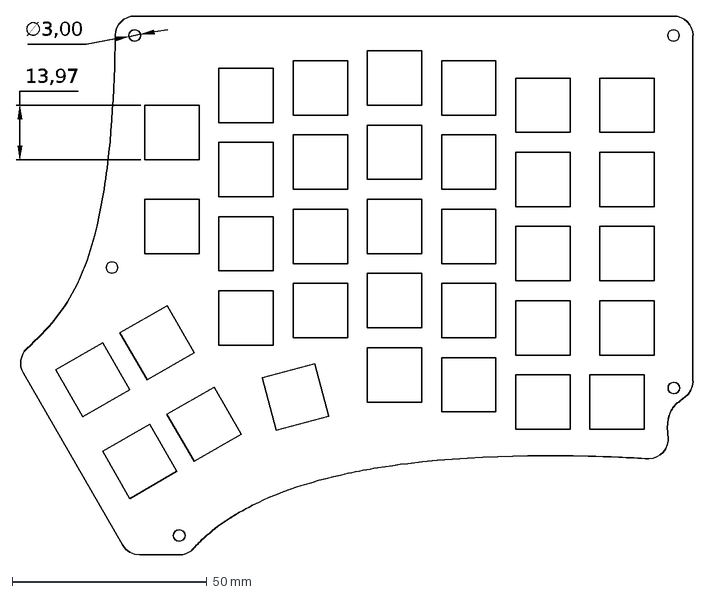
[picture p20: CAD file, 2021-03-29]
redox/case/RedoxRev2Top_2d.dxf
13,97
∅3,00

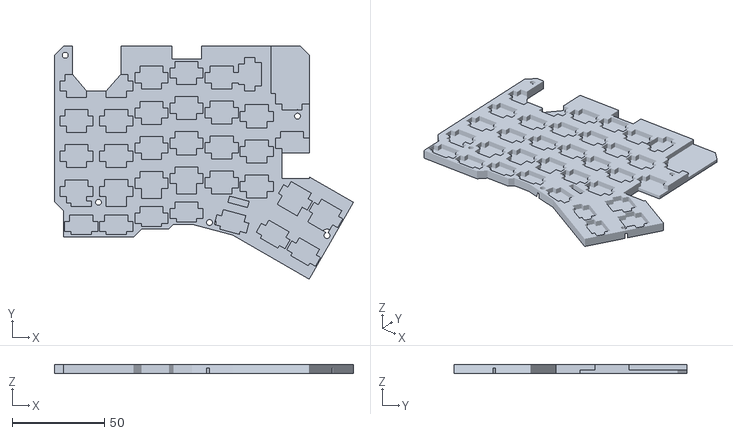
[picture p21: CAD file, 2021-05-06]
redox-w/rev2.0WHS/case/BackplateL.stl
162.2 x 126.5 x 5.00

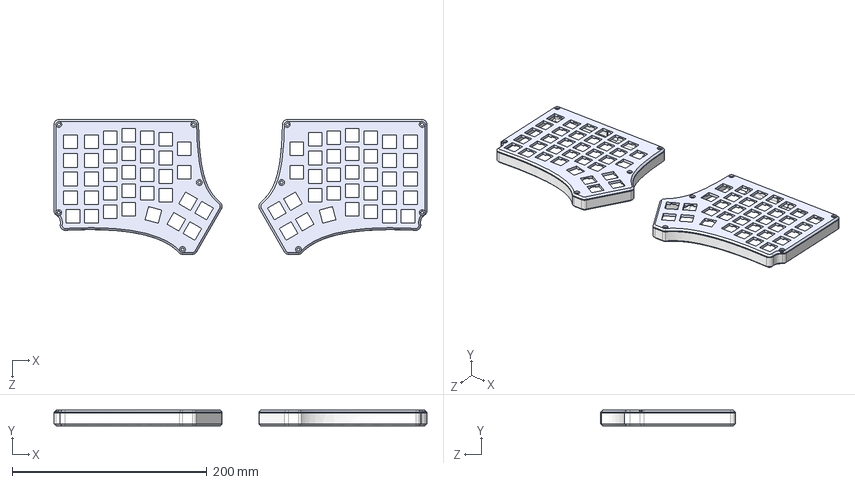
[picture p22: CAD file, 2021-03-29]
redox/case/RedoxRev2.step
382.8 x 16.0 x 138.4 mm

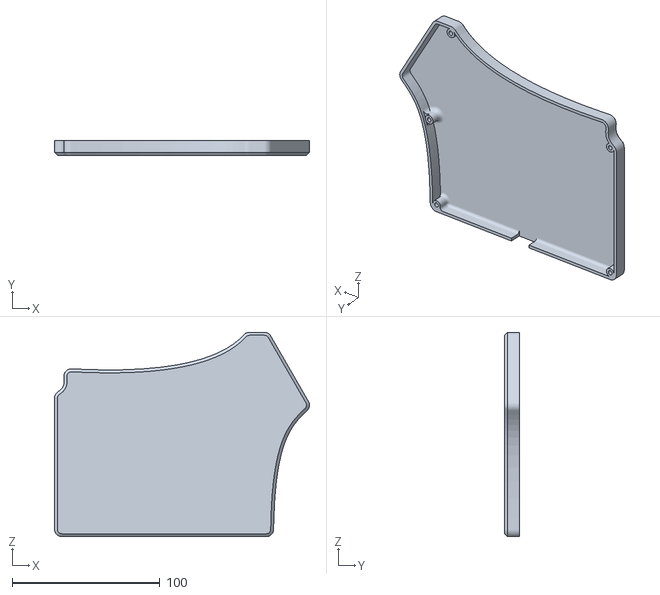
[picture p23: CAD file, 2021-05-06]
redox-w/rev1.0W/case/RedoxWirelessRev1BottomLeft.STL
172.6 x 10.0 x 138.4

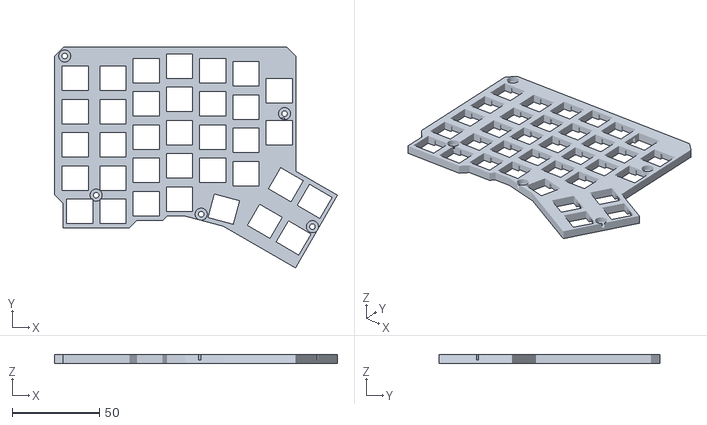
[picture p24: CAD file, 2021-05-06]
redox-w/rev2.0WHS/case/FrontplateL.stl
162.2 x 126.5 x 5.00

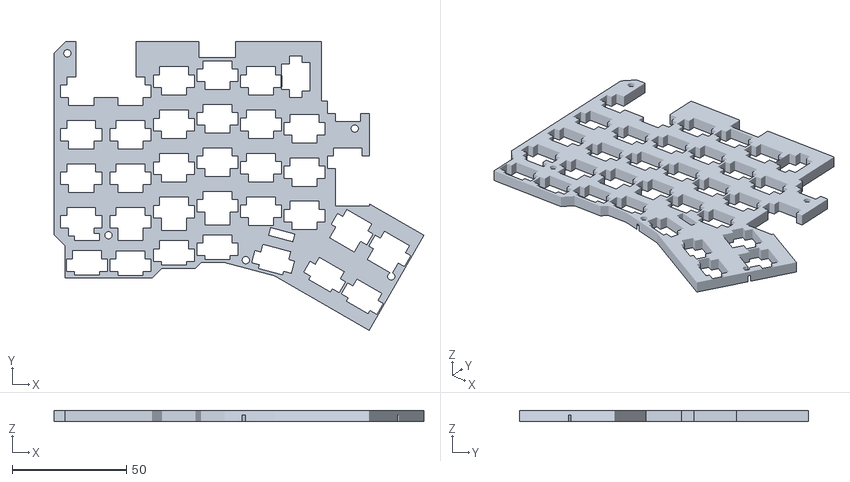
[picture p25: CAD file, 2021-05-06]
redox-w/rev2.0WHS/case/OpenBackplateL.stl
162.2 x 126.5 x 5.00

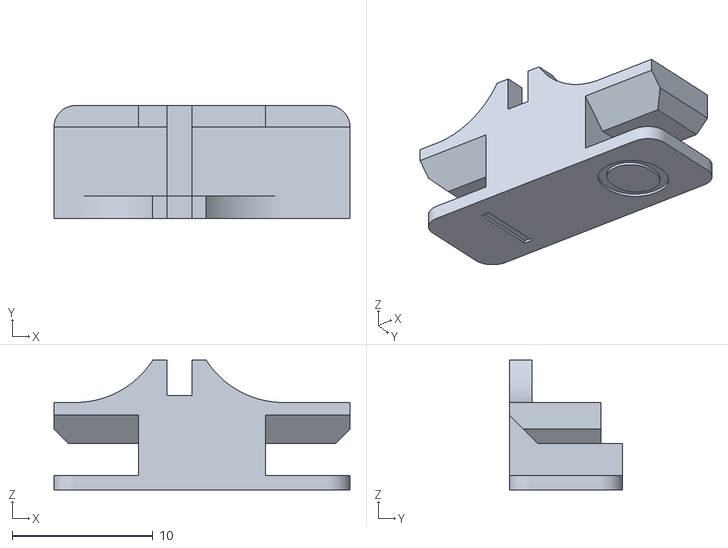
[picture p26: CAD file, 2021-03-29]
redox-w/rev1.0W/case/RedoxWirelessSwitch.stl
21.0 x 8.00 x 9.20

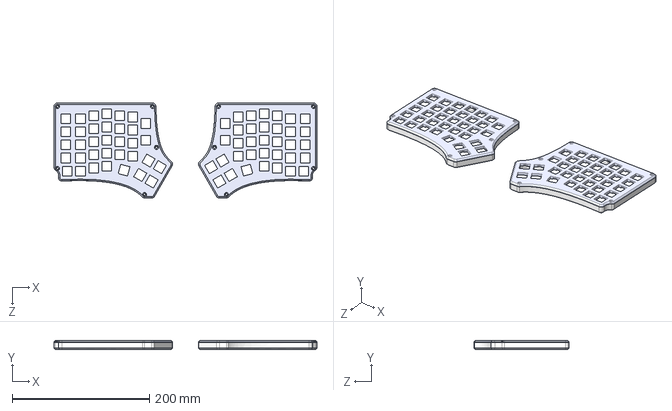
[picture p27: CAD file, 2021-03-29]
redox-w/rev1.0W/case/RedoxWirelessRev1.0Test.step
382.8 x 13.0 x 138.4 mm

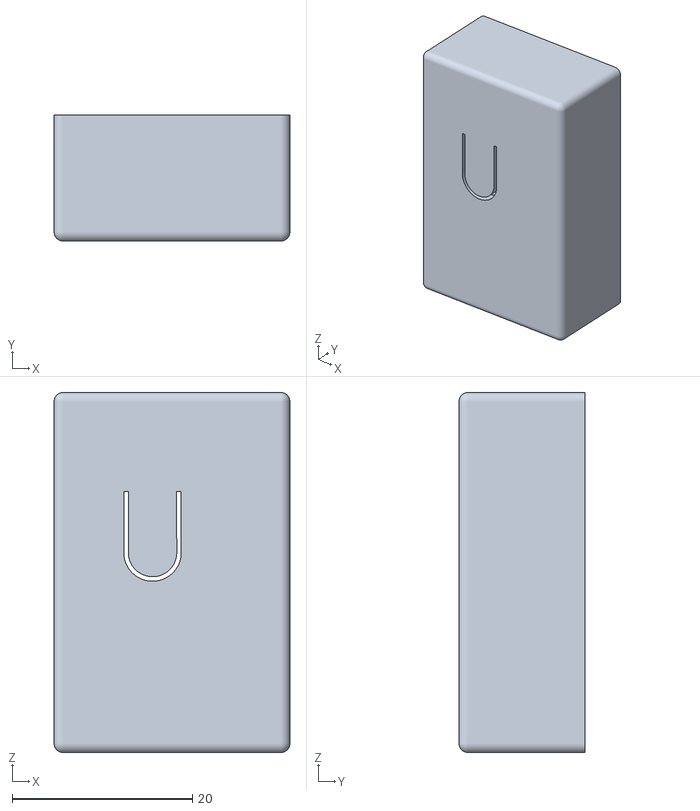
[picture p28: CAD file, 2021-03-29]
redox-w/rev1.0W/case/RedoxWirelessRev1ReceiverBottom.stl
26.2 x 14.0 x 40.0

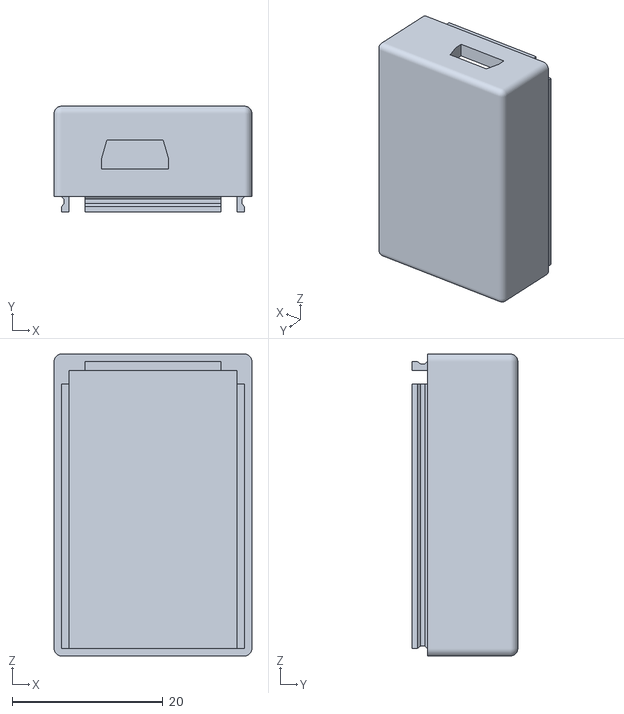
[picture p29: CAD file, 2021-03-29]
redox-w/rev1.0W/case/RedoxWirelessRev1ReceiverTop.stl
26.2 x 14.0 x 40.0

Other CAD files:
redox-w/rev1.0W/case/RedoxWirelessRev1TopRight.STL
redox-w/rev1.0W/case/RedoxWirelessRev1BottomRight.STL
redox-w/rev2.0WHS/case/RedoxRev2.0WHSCasev15.f3d

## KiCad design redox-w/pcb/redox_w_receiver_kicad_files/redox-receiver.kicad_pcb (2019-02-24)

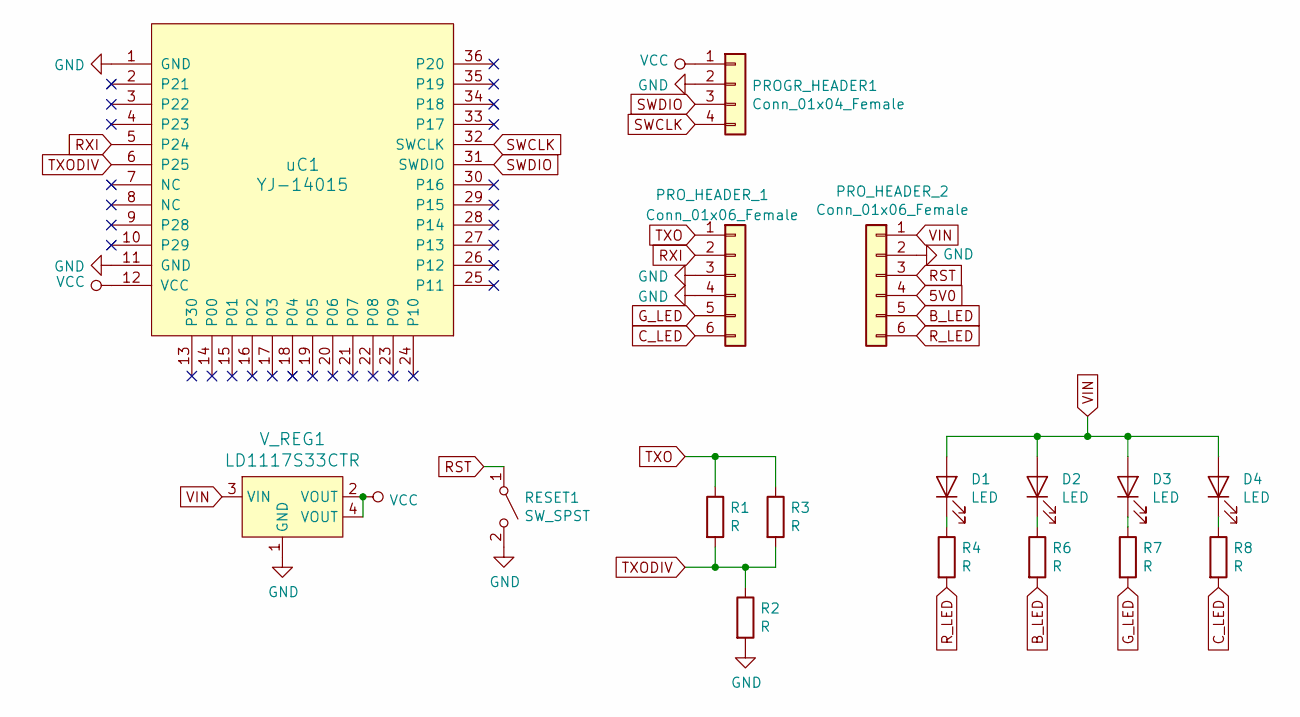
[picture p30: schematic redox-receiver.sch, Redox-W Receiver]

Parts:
D1, D2, D3, D4: LED; LED_0805_2012Metric_Pad1.15x1.40mm_HandSolder
PROGR_HEADER1: Conn_01x04_Female; PinHeader_1x04_P2.54mm_Vertical
PRO_HEADER_1, PRO_HEADER_2: Conn_01x06_Female; PinHeader_1x06_P2.54mm_Vertical
R1, R2, R3, R4, R6, R7, R8: R; R_0805_2012Metric_Pad1.15x1.40mm_HandSolder
RESET1: SW_SPST; SW_PUSH_6mm_H4.3mm
V_REG1: LD1117S33CTR; SOT-223; MPN LD1117S33CTR; Digi-Key_PN 497-1241-1-ND
uC1: YJ-14015; MY-YJ-14015-Module

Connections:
5V0: PRO_HEADER_2.4
B_LED: PRO_HEADER_2.5, R6.2
C_LED: PRO_HEADER_1.6, R8.2
GND: PROGR_HEADER1.2, PRO_HEADER_1.3, PRO_HEADER_1.4, PRO_HEADER_2.2, R2.2, RESET1.2 (B), V_REG1.1 (GND), uC1.1 (GND), uC1.11 (GND)
G_LED: PRO_HEADER_1.5, R7.2
unnamed: D1.1 (K), R4.1
unnamed: D2.1 (K), R6.1
unnamed: D3.1 (K), R7.1
unnamed: D4.1 (K), R8.1
RST: PRO_HEADER_2.3, RESET1.1 (A)
RXI: PRO_HEADER_1.2, uC1.5 (P24)
R_LED: PRO_HEADER_2.6, R4.2
SWCLK: PROGR_HEADER1.4, uC1.32 (SWCLK)
SWDIO: PROGR_HEADER1.3, uC1.31 (SWDIO)
TXO: PRO_HEADER_1.1, R1.1, R3.1
TXODIV: R1.2, R2.1, R3.2, uC1.6 (P25)
VCC: PROGR_HEADER1.1, V_REG1.2 (VOUT), V_REG1.4 (VOUT), uC1.12 (VCC)
VIN: D1.2 (A), D2.2 (A), D3.2 (A), D4.2 (A), PRO_HEADER_2.1, V_REG1.3 (VIN)

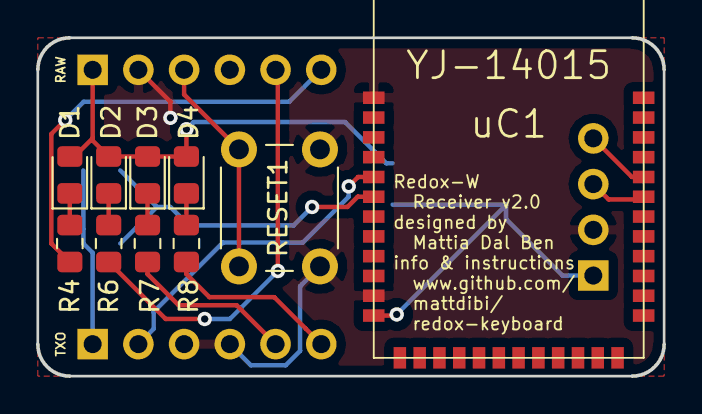
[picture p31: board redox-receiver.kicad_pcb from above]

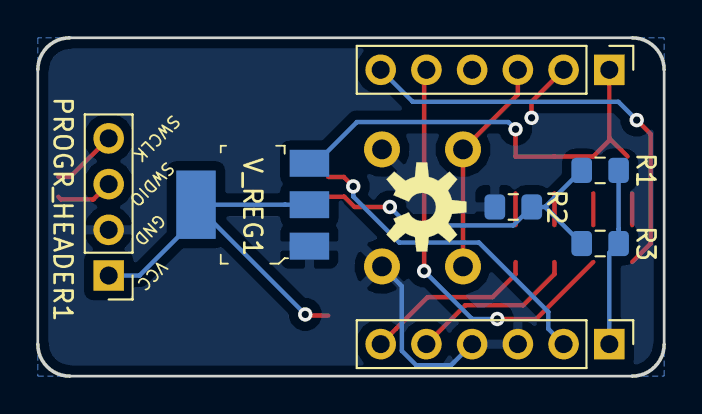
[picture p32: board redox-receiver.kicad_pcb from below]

Board: 2 copper layers, 34.8 x 18.8 mm, 17 parts (7 on the bottom side), 17 nets.

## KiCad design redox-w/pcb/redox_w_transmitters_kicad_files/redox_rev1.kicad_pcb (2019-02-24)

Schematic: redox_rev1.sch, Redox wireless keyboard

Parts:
BT_LEFT1: Battery_Cell; BatteryHolder_Keystone_3034_1x20mm
BT_RIGHT1: Battery_Cell; BatteryHolder_Keystone_3034_1x20mm
D0, D1, D2, D3, D4, D5, D6, D10, D11, D12, D13, D14, D15, D16, D20, D21, D22, D23, D24, D25, D26, D30, D31, D32, D33, D34, D35, D36, D40, D41, D42, D43, D44, D45, D46: D; Diode-dual
J_PROG_PORT1: Conn_01x04_Male; PinHeader_1x04_P2.54mm_Vertical
K0, K1, K2, K3, K4, K5, K6, K10, K11, K12, K13, K14, K15, K16, K20, K21, K22, K23, K24, K25, K26, K30, K31, K32, K33, K34, K35, K36, K40, K41, K42, K43, K44, K45, K46: KEYSW; Hybrid_PCB_100H_Dual_hole-nosilk
SW_LEFT1: SW_SPDT; SW_SPDT_CK-JS102011SAQN
SW_RIGHT1: SW_SPDT; SW_SPDT_CK-JS102011SAQN
U_LEFT1: Core51822B; YJ-14015-Modul
U_RIGHT1: Core51822B; YJ-14015-Modul

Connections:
GND: BT_LEFT1.2, BT_RIGHT1.2, J_PROG_PORT1.4, U_LEFT1.1, U_LEFT1.11, U_RIGHT1.1, U_RIGHT1.11
unnamed: BT_LEFT1.1, SW_LEFT1.2
unnamed: BT_RIGHT1.1, SW_RIGHT1.2
unnamed: D0.2 (A), K0.2
unnamed: D1.2 (A), K1.2
unnamed: D2.2 (A), K2.2
unnamed: D3.2 (A), K3.2
unnamed: D4.2 (A), K4.2
unnamed: D5.2 (A), K5.2
unnamed: D6.2 (A), K6.2
unnamed: D10.2 (A), K10.2
unnamed: D11.2 (A), K11.2
unnamed: D12.2 (A), K12.2
unnamed: D13.2 (A), K13.2
unnamed: D14.2 (A), K14.2
unnamed: D15.2 (A), K15.2
unnamed: D16.2 (A), K16.2
unnamed: D20.2 (A), K20.2
unnamed: D21.2 (A), K21.2
unnamed: D22.2 (A), K22.2
unnamed: D23.2 (A), K23.2
unnamed: D24.2 (A), K24.2
unnamed: D25.2 (A), K25.2
unnamed: D26.2 (A), K26.2
unnamed: D30.2 (A), K30.2
unnamed: D31.2 (A), K31.2
unnamed: D32.2 (A), K32.2
unnamed: D33.2 (A), K33.2
unnamed: D34.2 (A), K34.2
unnamed: D35.2 (A), K35.2
unnamed: D36.2 (A), K36.2
unnamed: D40.2 (A), K40.2
unnamed: D41.2 (A), K41.2
unnamed: D42.2 (A), K42.2
unnamed: D43.2 (A), K43.2
unnamed: D44.2 (A), K44.2
unnamed: D45.2 (A), K45.2
unnamed: D46.2 (A), K46.2
SWCLK: J_PROG_PORT1.2, U_LEFT1.32, U_RIGHT1.32
SWDIO: J_PROG_PORT1.3, U_LEFT1.31, U_RIGHT1.31
VCC: J_PROG_PORT1.1, SW_LEFT1.1, SW_RIGHT1.1, U_LEFT1.12, U_RIGHT1.12
col0: K0.1, K10.1, K20.1, K30.1, K40.1, U_LEFT1.24, U_RIGHT1.13
col1: K1.1, K11.1, K21.1, K31.1, K41.1, U_LEFT1.23, U_RIGHT1.14
col2: K2.1, K12.1, K22.1, K32.1, K42.1, U_LEFT1.21, U_RIGHT1.16
col3: K3.1, K13.1, K23.1, K33.1, K43.1, U_LEFT1.20, U_RIGHT1.17
col4: K4.1, K14.1, K24.1, K34.1, K44.1, U_LEFT1.19, U_RIGHT1.18
col5: K5.1, K15.1, K25.1, K35.1, K45.1, U_LEFT1.18, U_RIGHT1.19
col6: K6.1, K16.1, K26.1, K36.1, K46.1, U_LEFT1.17, U_RIGHT1.20
row0: D0.1 (K), D1.1 (K), D2.1 (K), D3.1 (K), D4.1 (K), D5.1 (K), D6.1 (K), U_LEFT1.35, U_RIGHT1.2
row1: D10.1 (K), D11.1 (K), D12.1 (K), D13.1 (K), D14.1 (K), D15.1 (K), D16.1 (K), U_LEFT1.34, U_RIGHT1.3
row2: D20.1 (K), D21.1 (K), D22.1 (K), D23.1 (K), D24.1 (K), D25.1 (K), D26.1 (K), U_LEFT1.33, U_RIGHT1.4
row3: D30.1 (K), D31.1 (K), D32.1 (K), D33.1 (K), D34.1 (K), D35.1 (K), D36.1 (K), U_LEFT1.28, U_RIGHT1.9
row4: D40.1 (K), D41.1 (K), D42.1 (K), D43.1 (K), D44.1 (K), D45.1 (K), D46.1 (K), U_LEFT1.27, U_RIGHT1.10

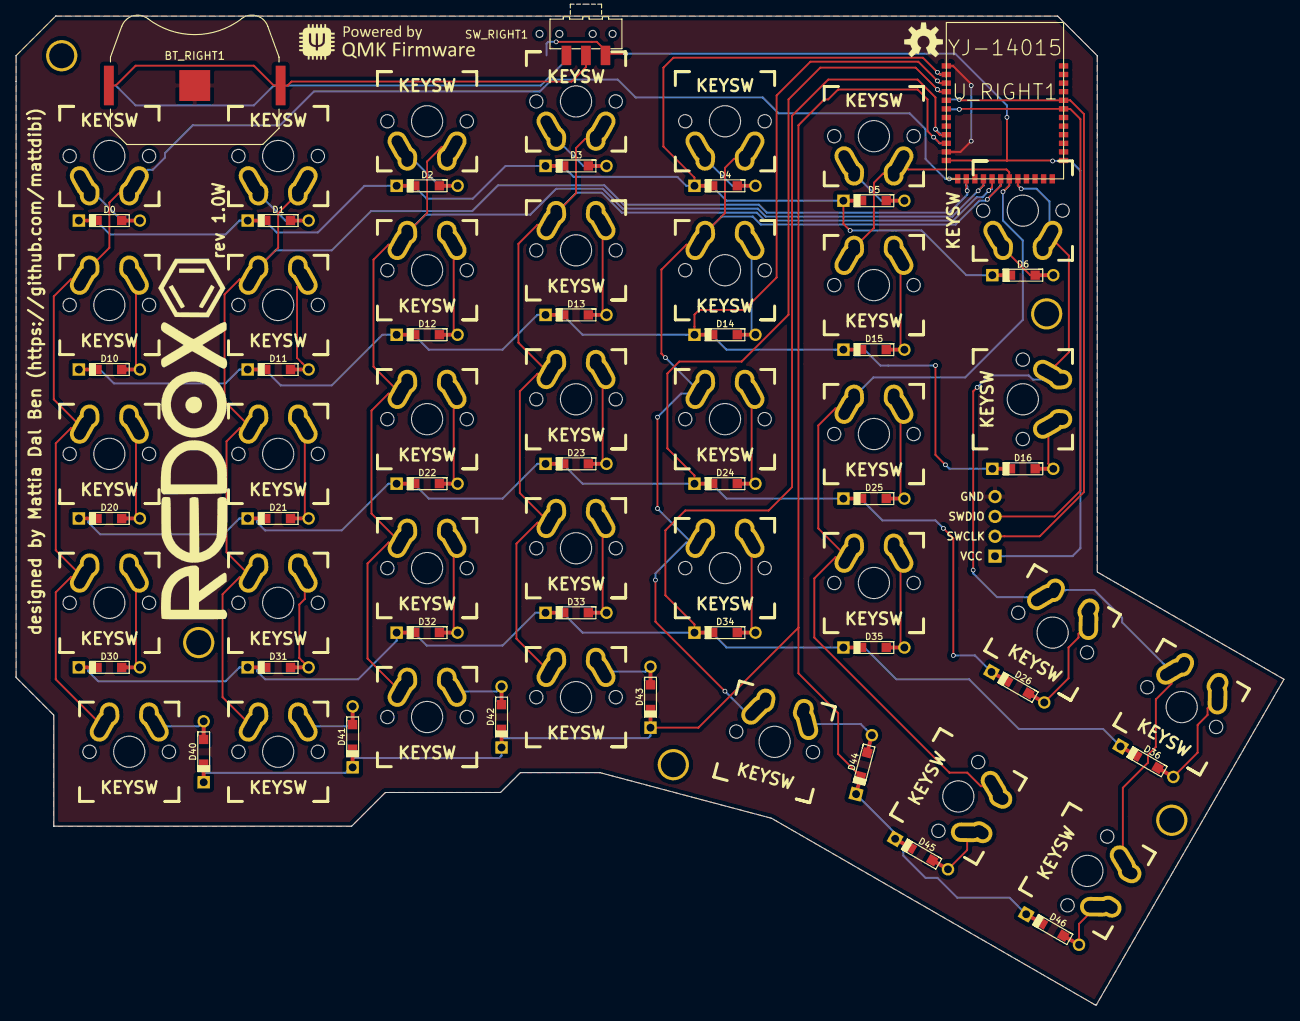
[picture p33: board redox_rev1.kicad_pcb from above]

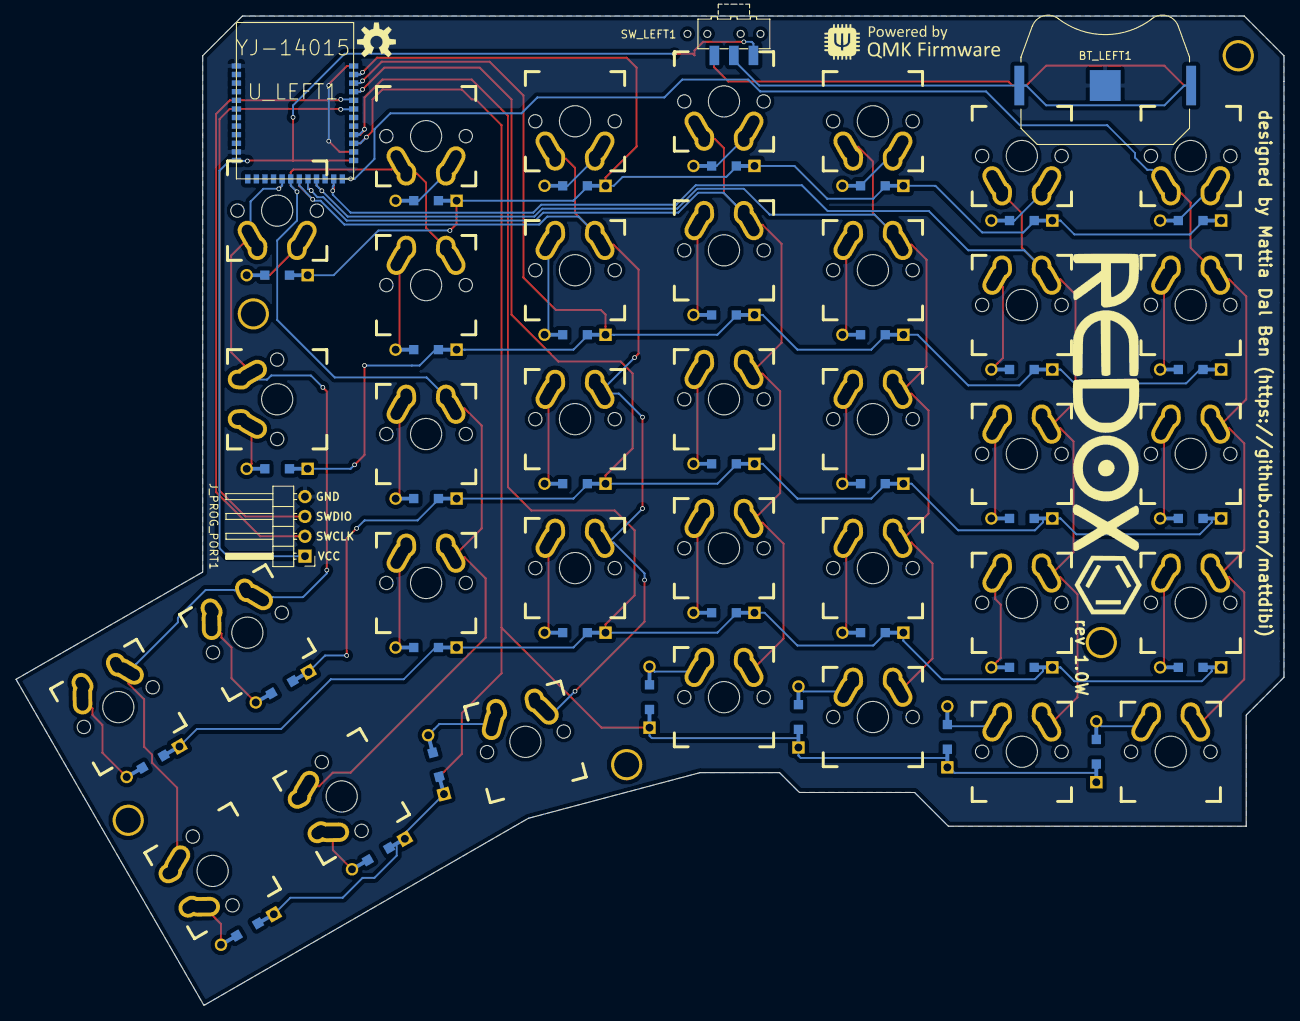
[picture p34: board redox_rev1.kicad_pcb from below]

Board: 2 copper layers, 162.2 x 126.5 mm, 82 parts (4 on the bottom side), 53 nets.

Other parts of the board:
HOLE_M3, HOLE_M3#2, HOLE_M3#3, HOLE_M3#4, HOLE_M3#5: VAL**; HOLE_M3

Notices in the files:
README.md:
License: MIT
